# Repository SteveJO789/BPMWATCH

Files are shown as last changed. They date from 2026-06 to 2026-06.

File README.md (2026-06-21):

# BPMWATCH

BPMWATCH is a two-node wearable Radar MVP built with ESP32, B&T BU01/DW1000 ranging, GY-511 heading and motion sensing, MAX30102 heart-rate sensing, ESP-NOW Peer data, and a no-CS ZJY-IPS130-V2.0 ST7789 240x240 display.

Each node places itself at the center of a north-up radar screen and shows the other node as a distance-scaled dot. The direction is a movement-based visual estimate, not a true UWB angle measurement.

## Current Architecture

The product has two equal Radar Nodes:

| Product node | ESP32 STA MAC | Fixed DW1000 role |
|---|---|---|
| Node A | `0C:8A:D3:7C:E5:A4` | Anchor |
| Node B | `1C:75:C4:F4:E9:D4` | Tag |

Anchor and Tag are radio protocol roles only. There is no application-level Master or Slave.

The two links have separate responsibilities:

- **UWB:** calibrated distance ranging only.
- **ESP-NOW:** Peer BPM and accepted reciprocal-bearing estimates.

Production firmware will not create a Wi-Fi AP, webserver, or browser dashboard. The existing AP monitor remains only in the diagnostic `uwb_pair_test`.

See:

- [Architecture workflow](radar_2d_map_architecture.svg)
- [Architecture](docs/architecture.md)
- [Radar MVP design spec](docs/superpowers/specs/2026-06-21-radar-2d-map-mvp-design.md)
- [Test plan](docs/test-plan.md)

## Hardware Per Node

- ESP32-WROOM-32
- B&T BU01 DW1000 LDO UWB breakout
- ZJY-IPS130-V2.0 IPS TFT LCD 240x240 ST7789 display without a CS pin
- GY-511 / LSM303DLHC accelerometer and compass
- MAX30102 heart-rate sensor
- 602030 Li-Po battery
- TP4056 Type-C charger with protection
- TPS63802 3.3V buck-boost supply
- Power switch, decoupling capacitors, and enclosure

Both nodes use the same buses and pin map. Only the MAC address and fixed DW1000 role differ.

## Radar Behavior

- North-up display with the current node at `(120,120)`.
- UWB distance is filtered with an EMA and mapped to an automatic `5/10/20/40m` range.
- GY-511 acceleration and compass heading provide a visual movement-bearing heuristic.
- Decreasing distance places the Peer along the estimated movement bearing.
- Increasing distance places the Peer approximately 180 degrees behind that bearing.
- ESP-NOW mirrors an accepted bearing to the other display with a reciprocal 180-degree transform.
- If UWB is lost, the last Peer dot remains as an inactive outline.
- If ESP-NOW is stale, radar ranging continues and Peer BPM displays `--`.

## Repository Map

- `firmware/radar_node`: approved production target; implementation pending.
- `firmware/tests/uwb_pair_test`: working two-node UWB diagnostic with AP monitor.
- `firmware/tests`: focused hardware bring-up projects.
- `firmware/master` and `firmware/slave`: deprecated pre-pivot production scaffolds; scheduled for legacy relocation during firmware implementation.
- `firmware/sim/wokwi`: legacy three-node UI simulation; not current Radar MVP validation.
- `lib/DW1000`: vendored ESP32-compatible DW1000 library.
- `docs/legacy/three-node`: superseded triangle-map documents and diagrams.
- `test-logs`: current two-node bench evidence.

## Current Status

Completed:

- ESP32 identity and STA MAC capture.
- ZJY-IPS130-V2.0 display bring-up using dedicated `SPIClass`, manual reset, `SPI_MODE3`, and 8 MHz display transactions.
- GY-511 I2C discovery, initialization, and heading output.
- MAX30102 raw IR and BPM calculation bring-up.
- Real Node A to Node B DW1000 ranging.
- Antenna delay `16555`, five-sample application median filter, and recovery behavior.
- Two-node Radar architecture, glossary, workflow SVG, and design specification.

Next implementation milestone:

1. Create the shared `firmware/radar_node` PlatformIO project.
2. Integrate UWB range callbacks without the production AP monitor.
3. Add GY-511 movement-bearing estimation and axis mapping.
4. Add ESP-NOW Peer BPM and reciprocal bearing.
5. Render and bench-test the radar on both ST7789 displays.

## Diagnostic Build

On this Windows machine, PlatformIO is available through:

```powershell
& "$env:USERPROFILE\.platformio\penv\Scripts\platformio.exe" run -d firmware\tests\uwb_pair_test -e master -e tag
```

The diagnostic environments retain the literal names `master` and `tag` for compatibility with tested code. They map to Node A/Anchor and Node B/Tag.

## Electrical Safety

- Keep all ESP32, DW1000, ST7789, GY-511, and MAX30102 signal levels 3.3V-compatible.
- Confirm the exact BU01 breakout power-input label before applying power.
- Keep the no-CS ST7789 on dedicated HSPI; do not share the DW1000 default SPI bus.
- Initialize ZJY-IPS130-V2.0 with `tft.init(240, 240, SPI_MODE3)` and call `tft.setSPISpeed(8000000)` after init.
- Feed Li-Po voltage to an ESP32 ADC only through a safe resistor divider.
- Verify TPS63802 stability during ESP32 radio and UWB current bursts.

## Historical Architecture

The former one-Master/two-Slave triangle map is no longer the product direction. Its documentation is retained under [`docs/legacy/three-node`](docs/legacy/three-node/README.md).

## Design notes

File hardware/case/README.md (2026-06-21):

# Two-Node Radar Case Design

Node A and Node B require equivalent wearable enclosures for ESP32, BU01, ST7789, GY-511, MAX30102, and the protected battery power chain.

Mechanical requirements:

- Keep ESP32 and BU01 antenna regions clear of metal and the battery.
- Keep the MAX30102 window aligned with stable skin contact.
- Mount GY-511 flat with its X/Y orientation recorded relative to display top.
- Expose the ST7789 without loading its flex cable or header.
- Provide access to charging, power, reset/boot, and any future interaction button.
- Leave room for regulator and radio decoupling capacitors.

Use the same external orientation for both nodes where possible so axis mapping and radar behavior remain consistent.

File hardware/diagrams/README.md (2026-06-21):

# Hardware Diagrams

The current system workflow is [`radar_2d_map_architecture.svg`](../../radar_2d_map_architecture.svg).

New diagrams must use Node A and Node B as equal Radar Nodes. `Anchor` and `Tag` may appear only as fixed DW1000 radio roles. Superseded three-node diagrams belong under [`docs/legacy/three-node`](../../docs/legacy/three-node/README.md).

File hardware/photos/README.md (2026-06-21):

# Two-Node Radar Hardware Photos

Store dated photos for both Node A and Node B. Each photo set should show:

- Node label and ESP32 STA MAC
- BU01 antenna orientation
- ST7789 wiring and display orientation
- GY-511 axis orientation relative to display top
- MAX30102 placement
- I2C, default SPI, and dedicated HSPI wiring
- Battery, charger, regulator, switch, and decoupling

Do not label new photos as Master or Slave. Historical photos may keep their original labels if the caption marks them as pre-pivot evidence.

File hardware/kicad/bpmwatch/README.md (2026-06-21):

# BPMWATCH KiCad Schematic Status

The KiCad files in this folder predate the 2026-06-21 two-node Radar pivot. They describe an unequal Master/repeated-Slave concept and are not the current wiring source of truth.

Use [`docs/pin-map.md`](../../../docs/pin-map.md), [`docs/wiring-node-a.md`](../../../docs/wiring-node-a.md), and [`docs/wiring-node-b.md`](../../../docs/wiring-node-b.md) for current bench wiring.

## Required Schematic Revision

The next schematic revision must contain two equivalent Radar Nodes:

- ESP32-WROOM-32
- BU01/DW1000 on default SPI
- No-CS ST7789 on dedicated HSPI
- GY-511 and MAX30102 on shared I2C GPIO21/22
- Protected Li-Po charging and TPS63802 3.3V rail

Only the node identity and fixed DW1000 Anchor/Tag role differ.

## Existing Artifact Use

The existing schematic and exports remain historical module-level interconnect references. They are not production PCB signoff, and their Master/Slave labels must not be copied into new designs.

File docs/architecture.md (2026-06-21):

# Two-Node Radar Architecture

BPMWATCH contains two equal wearable Radar Nodes. Each node displays itself at the center and the other node as its Peer.

```text
Node A / DW1000 Anchor  <--- calibrated UWB distance --->  Node B / DW1000 Tag
          |                                                       |
          +<------ ESP-NOW: Peer BPM + bearing estimate -------->+
```

Anchor and Tag are fixed DW1000 radio roles. They do not create an application-level Master/Slave hierarchy.

## Per-Node Data Flow

```text
DW1000 distance ------\
GY-511 heading --------+--> Radar state --> north-up ST7789 display
GY-511 acceleration --/

Local MAX30102 BPM --> ESP-NOW --> Peer display
Accepted bearing ----> ESP-NOW --> reciprocal angle on Peer display
```

## UWB Responsibility

UWB provides distance only. Production firmware retains the proven Anchor/Tag ranging flow, antenna delay `16555`, five-sample median filter, and recovery behavior.

UWB does not provide direction. The displayed bearing is a visual estimate derived from current-node movement and heading.

## Movement Bearing

The node uses mapped GY-511 acceleration axes to estimate a short-lived horizontal acceleration direction, then rotates that direction into a north-up compass frame.

When cumulative UWB distance changes by more than `0.25m` during accepted movement:

- Decreasing range places the Peer along the movement bearing.
- Increasing range places the Peer approximately 180 degrees behind it.
- Stable range keeps the previous Peer bearing.

If one node accepts a bearing, ESP-NOW sends it to the Peer. The Peer applies `+180 degrees` so both displays update when only one node moves.

## ESP-NOW Responsibility

ESP-NOW carries small bidirectional status packets:

- Peer BPM and validity
- Accepted bearing and validity
- Node ID, packet version, and sequence

It uses Wi-Fi station mode without creating an AP or browser UI. ESP-NOW freshness and UWB freshness are tracked separately.

## Display Meaning

- North is always at the top.
- The current node is always at the center.
- The Peer radius represents filtered UWB distance within the active `5/10/20/40m` band.
- The Peer angle is an estimate, not a measured UWB angle or geographic position.
- A gray outline dot means the last UWB position is being retained after link loss.

## Historical Architecture

The former three-node triangle solver and `TeamMapPacket` flow are superseded. Historical documents are under [`legacy/three-node`](legacy/three-node/README.md).

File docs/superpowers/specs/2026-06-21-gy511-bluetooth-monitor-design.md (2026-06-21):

# GY-511 Bluetooth Serial Monitor Design

## Goal

Allow the soldered ESP32 and GY-511 test assembly to be monitored from Windows after USB is disconnected and the board is powered from the TPS63802 3.3 V rail.

## Scope

- Modify only `firmware/tests/gy511_test/src/main.cpp`.
- Keep the existing GY-511 initialization, register reads, calculations, and 500 ms reporting interval.
- Keep USB `Serial` output available for bench diagnosis.
- Add Bluetooth Classic Serial Port Profile output for this diagnostic sketch only.
- Do not add Bluetooth to production Radar Node firmware and do not replace the planned ESP-NOW peer-data protocol.

## Runtime Design

The sketch creates an ESP32 `BluetoothSerial` endpoint named `BPMWATCH-GY511` using Secure Simple Pairing (SSP) in Just Works mode. Each startup, status, error, and sensor-data line is written to both USB `Serial` and Bluetooth serial.

Bluetooth startup failure must not block I2C setup or GY-511 sampling. The sketch reports the failure over USB and continues operating as the original USB-only sensor test.

## Data Flow

1. The ESP32 initializes USB serial.
2. It enables SSP before starting Bluetooth SPP.
3. It initializes I2C and the GY-511.
4. Every 500 ms, it reads accelerometer and magnetometer registers and calculates heading.
5. It formats one complete diagnostic line and sends the same line to both serial transports.

## Power And Connection Procedure

1. Isolate or switch off the TPS63802 output before connecting USB for upload so two regulators do not drive the same 3.3 V rail.
2. Upload the diagnostic firmware over USB.
3. Disconnect USB completely.
4. Restore TPS63802 power.
5. Pair Windows with `BPMWATCH-GY511`. No PIN is required.
6. Open the outgoing Bluetooth SPP COM port at 115200 baud. The SPP transport does not depend on UART baud electrically, but 115200 keeps terminal configuration consistent with the USB monitor.

## Verification

- The PlatformIO environment builds successfully.
- Source-level checks confirm the device name, SSP-before-startup ordering, absence of legacy PIN configuration, and dual-output behavior.
- With hardware, Windows can pair and receive GY-511 readings while USB is disconnected.
- If Bluetooth initialization fails, USB still reports the failure and GY-511 sampling continues.

## Non-Goals

- BLE support.
- A phone application or browser dashboard.
- Wi-Fi AP, webserver, or Telnet logging.
- Changes to production node-to-node communications.

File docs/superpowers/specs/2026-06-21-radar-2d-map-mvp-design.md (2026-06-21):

# Radar 2D Map MVP Design

Date: 2026-06-21

## Status

Approved design for implementation.

## Goal

Replace the product's three-node triangle-map architecture with a two-node wearable radar MVP. Each node places itself at the center of a north-up ST7789 display and shows the other node as a dot using UWB distance plus a movement-based bearing estimate.

The MVP prioritizes useful visual behavior over positioning accuracy.

## Product Decisions

- The product has exactly two equal Radar Nodes. There is no application-level master.
- Node A uses STA MAC `0C:8A:D3:7C:E5:A4` and the fixed DW1000 Anchor radio role.
- Node B uses STA MAC `1C:75:C4:F4:E9:D4` and the fixed DW1000 Tag radio role.
- Anchor and Tag are radio roles only. Product UI and documentation use Node A, Node B, current node, and Peer.
- Both nodes use ESP32, B&T BU01/DW1000, GY-511/LSM303DLHC, MAX30102, and a no-CS ZJY-IPS130-V2.0 ST7789 240x240 display.
- The existing working two-node DW1000 ranging flow, calibration, filtering, and recovery behavior remain the baseline.
- ESP-NOW carries Peer BPM and accepted bearing estimates. It does not create a Wi-Fi AP or browser UI.
- The existing `firmware/tests/uwb_pair_test` remains an unchanged diagnostic test, including its AP monitor.
- The superseded three-node production code and related artifacts move under a clearly marked legacy location during implementation.

## Non-Goals

- Three-node ranging or triangle solving
- `TeamMapPacket` or shared team-map broadcasting
- True 2D positioning
- DW1000 Angle-of-Arrival
- GPS coordinates
- Wi-Fi AP, webserver, or browser dashboard in production firmware
- Dynamic Anchor/Tag role switching
- High-accuracy inertial dead reckoning
- Accuracy warning UI
- OLED support

## Repository Shape

The canonical production firmware will be:

```text
firmware/radar_node/
|-- platformio.ini
`-- src/
    |-- main.cpp
    |-- NodeConfig.h
    |-- UwbPeerRanging.h
    |-- UwbPeerRanging.cpp
    |-- Gy511Motion.h
    |-- Gy511Motion.cpp
    |-- HeartRateSensor.h
    |-- HeartRateSensor.cpp
    |-- PeerLink.h
    |-- PeerLink.cpp
    |-- RadarMap.h
    `-- RadarMap.cpp
```

PlatformIO provides two environments from the same source:

- `node_a_anchor`
- `node_b_tag`

Build flags select the node ID, Peer STA MAC, and fixed DW1000 role. Node behavior outside the radio role is symmetric.

## Hardware and Buses

Both nodes use the same pin contract:

| Device | Interface | ESP32 pins |
|---|---|---|
| BU01/DW1000 | Default SPI | SCK 18, MISO 19, MOSI 23, CS 5, IRQ 34, RST 4 |
| ST7789 no-CS | Dedicated HSPI | SCK 14, MOSI 13, BLC 25, DC 26, RST 27 |
| GY-511 | I2C | SDA 21, SCL 22 |
| MAX30102 | Shared I2C | SDA 21, SCL 22 |

The display must remain on its dedicated `SPIClass`; the no-CS ST7789 must not share the DW1000 bus.

The bench-confirmed display initialization contract is:

1. Drive RES high, low, then high with 50 ms holds.
2. Start the dedicated HSPI bus.
3. Call `tft.init(240, 240, SPI_MODE3)`.
4. Call `tft.setSPISpeed(8000000)` after init so subsequent transactions use 8 MHz.

## Core Data Structures

The Radar module starts with the required public contracts:

```cpp
struct RadarInput {
  float distanceM;
  float headingDeg;
  float accelX;
  float accelY;
  float accelZ;
  bool linkOk;
  unsigned long timestamp;
};

struct RadarState {
  float peerAngleDeg;
  float peerDistanceM;
  float lastDistanceM;
  float smoothedDistanceM;
  bool hasAngle;
  bool hidePeerDot;
  unsigned long lastUpdate;
};
```

Internal state may extend `RadarState` or remain private to `RadarMap` for movement filtering, distance baseline, auto-range hysteresis, last valid link state, and accepted-bearing publication. Peer BPM and ESP-NOW freshness remain outside `RadarInput` because they do not affect radar geometry.

## Sensor Sampling

- MAX30102 sampling remains near 20 ms so beat detection is not slowed by UI or packet timing.
- GY-511 is sampled independently from the 150 ms display cadence.
- GY-511 and MAX30102 share I2C without blocking the UWB ranging loop.
- Configurable compile-time axis mapping supports X/Y swap and sign inversion.
- The initial mounting convention is mapped `+Y = display top`.

## Movement Bearing Heuristic

The GY-511 does not contain a gyroscope, so the MVP does not claim reliable inertial navigation. It uses a short-lived horizontal-acceleration direction as a visual movement heuristic:

1. Apply axis mapping.
2. Low-pass accelerometer axes to estimate gravity.
3. Subtract gravity to obtain approximate linear acceleration.
4. Reject weak acceleration as stationary/noisy.
5. For accepted motion, compute the relative direction with `atan2(rightAccel, forwardAccel)`.
6. Add compass heading and normalize to produce a north-up movement bearing.
7. Keep the last accepted movement bearing while acceleration becomes weak.

The first implementation uses test-tunable constants for the gravity filter, motion threshold, confirmation samples, and motion hold time. Bench tests, not theoretical precision, determine their final values.

## Distance and Bearing Update

For each valid UWB distance:

```cpp
smoothedDistanceM = smoothedDistanceM * 0.75f + distanceM * 0.25f;
```

The first valid sample initializes the EMA directly to avoid ramping from zero.

The distance delta is cumulative since the last accepted bearing update, not merely the difference between adjacent 100-200 ms samples:

```cpp
delta = smoothedDistanceM - lastDistanceM;
```

When recent motion is valid and `abs(delta) > 0.25m`:

- `delta < 0`: target Peer angle is the movement bearing.
- `delta > 0`: target Peer angle is the movement bearing plus 180 degrees.
- Smooth toward the target with shortest-path angular smoothing and alpha `0.15`.
- Set the new smoothed distance as the next bearing baseline.
- Publish the accepted bearing to the Peer through ESP-NOW.

If no angle exists after the first valid range, initialize `peerAngleDeg` from the current compass heading. If distance change is below the threshold, keep the previous Peer angle.

Required helpers are:

- `normalizeAngle(float angle)`
- `angleDiff(float a, float b)`
- `smoothAngle(float current, float target, float alpha)`
- `mapDistanceToRadius(float distanceM)`
- `updateRadarState(RadarInput input)`
- `drawRadarMap()`

## Reciprocal Bearing

When one node accepts a new Peer bearing `theta`, it sends that estimate through ESP-NOW. The receiving node stores `normalizeAngle(theta + 180 degrees)` so both displays update even when only one node is moving.

The MVP primarily supports one moving node at a time. If both move and produce conflicting estimates, the newest locally received estimate wins; temporary dot movement is accepted as an MVP limitation.

## Auto-Range

The radar uses discrete ranges:

```text
5 m -> 10 m -> 20 m -> 40 m
```

- Expand immediately when smoothed distance exceeds 90% of the current range.
- Shrink one or more bands only after distance remains below 35% for 10 seconds.
- Do not change range while UWB is lost.
- Display the active range as `R:5m`, `R:10m`, `R:20m`, or `R:40m`.

The radial conversion is:

```cpp
radiusPx = constrain(
    (smoothedDistanceM / currentRangeM) * radarRadiusPx,
    5.0f,
    radarRadiusPx);
```

## Screen Geometry and Rendering

The only supported display is the no-CS ZJY-IPS130-V2.0 ST7789 240x240:

- Center: `(120, 120)`
- Radar radius: `100 px`
- North-up orientation
- Angle `0 degrees`: top
- Angle `90 degrees`: right

Polar conversion is:

```cpp
angleRad = peerAngleDeg * DEG_TO_RAD;
peerX = centerX + radiusPx * sinf(angleRad);
peerY = centerY - radiusPx * cosf(angleRad);
```

Each frame contains:

- Outer radar circle
- Inner half-range circle
- Horizontal and vertical cross lines
- `N` marker
- Green center dot for the current node
- Orange filled Peer dot when UWB is valid
- Gray outline Peer dot at the last known position when UWB is lost
- `WAITING` and no Peer dot before the first valid range
- Node label, UWB status, and active range at the top
- Peer BPM and distance at the bottom

The screen updates every 150 ms using one display SPI transaction per frame. Production rendering has no accuracy warning screen.

## UWB Ranging

Production code reuses the proven behavior from `firmware/tests/uwb_pair_test`:

- Fixed Anchor and Tag roles
- Antenna delay `16555`
- Application median filter with five samples
- Raw range, RX power, and quality callbacks
- Discovery recovery after 5 seconds
- Post-connection recovery after 15 seconds

The production module removes AP/webserver responsibilities. The diagnostic test retains them.

If no valid range arrives for 3 seconds, UI state becomes `UWB LOST`. The last known dot remains indefinitely until a new range arrives or the node restarts.

## ESP-NOW Peer Link

ESP-NOW is a bidirectional data link. It uses Wi-Fi station mode but does not create an AP.

```cpp
struct PeerStatusPacket {
  uint8_t version;
  uint8_t senderNodeId;
  uint16_t sequence;
  uint16_t bpm;
  float peerBearingDeg;
  uint8_t flags;
};
```

Flags indicate `bpmValid` and `bearingValid`.

- Send status every 500 ms.
- Send immediately after accepting a new bearing.
- Use local receive time for freshness rather than comparing unsynchronized node clocks.
- If no Peer packet arrives for 3 seconds, display `PEER BPM:--`.
- If MAX30102 has no valid finger/beat result, send `bpmValid=false`.
- UWB and ESP-NOW statuses are independent.

## Main Loop Scheduling

The loop remains non-blocking:

1. Poll DW1000 continuously.
2. Sample MAX30102 near every 20 ms.
3. Sample GY-511 at its configured sensor cadence.
4. Process ESP-NOW callbacks without blocking.
5. Update Radar state and render every 150 ms.
6. Send periodic Peer status every 500 ms.
7. Send accepted bearing events immediately.

No sensor sampling rate is reduced to control Serial output. Logs are throttled separately.

## Failure Behavior

| Failure | Radar behavior |
|---|---|
| No UWB range has ever arrived | No Peer dot; show `WAITING` |
| UWB range stale for 3 seconds | Keep last dot as gray outline; show `UWB LOST` |
| ESP-NOW stale for 3 seconds | Keep radar behavior; show `PEER BPM:--` |
| MAX30102 has no valid BPM | Send invalid BPM; Peer shows `PEER BPM:--` |
| GY-511 init/read failure | Keep distance and last angle; report sensor error through UI/Serial |
| Both nodes move simultaneously | Newest received bearing estimate wins; temporary instability is accepted |

## Documentation Migration

Implementation updates the current source of truth to the two-node architecture:

- `README.md`
- `docs/architecture.md`
- `docs/bom.md`
- `docs/pin-map.md`
- `docs/ranging-protocol.md`
- `docs/test-plan.md`
- wiring documentation
- main project plan

The new workflow diagram is `radar_2d_map_architecture.svg`. The old three-node SVG, triangle-map documentation, and production code move to a clearly named legacy area instead of being deleted.

## Verification

Automated tests cover:

- Angle normalization and wrap-around
- Shortest-path angle difference and smoothing
- EMA initialization and update
- Cumulative 0.25 m bearing baseline
- Motion gating and axis mapping
- Reciprocal bearing
- Auto-range hysteresis
- UWB-lost dot persistence
- ESP-NOW BPM freshness

Build gates are:

- `node_a_anchor`
- `node_b_tag`
- diagnostic `uwb_pair_test` master
- diagnostic `uwb_pair_test` tag

Bench verification covers:

1. Existing UWB pair ranging behavior
2. GY-511 axis mapping
3. Node A moving while Node B remains still
4. Node B moving while Node A remains still
5. Decreasing and increasing distance behavior
6. Bearing persistence when distance is stable
7. UWB loss with persistent inactive dot
8. ESP-NOW loss with invalid Peer BPM only
9. Bidirectional Peer BPM display
10. Auto-range bands and hysteresis

Results are stored in a new Radar MVP test log.

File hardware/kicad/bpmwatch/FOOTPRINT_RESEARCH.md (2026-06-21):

# Two-Node Radar Footprint Research

Research baseline: 2026-06-09. Architecture updated: 2026-06-21.

The current target has two equivalent Radar Nodes. Exact purchased breakouts must be measured before assigning production footprints.

| Module per node | Qty total | Footprint direction | Status |
|---|---:|---|---|
| ESP32-WROOM-32 | 2 | `RF_Module:ESP32-WROOM-32` only for a bare castellated module; use the exact dev-board headers otherwise | Confirm board variant |
| BU01 UWB breakout | 2 | Custom footprint from the exact BU01 package drawing | Confirm pad pattern and antenna keepout |
| ZJY-IPS130-V2.0 no-CS ST7789 240x240 | 2 | Measure the purchased header count, board outline, and mounting holes | Existing schematic symbol may not match |
| MAX30102 breakout | 2 | Custom breakout/header footprint from measured board | Confirm row spacing and orientation |
| GY-511 / LSM303DLHC | 2 | Header plus measured board outline | Confirm header direction and axis marking |
| Protected TP4056 Type-C module | 2 | Custom module footprint matching exact IN/BAT/OUT pads | Board variants differ |
| TPS63802 module | 2 | Custom breakout footprint; do not substitute bare-IC layout without a regulator redesign | Vendor/module not yet identified |
| 602030 Li-Po connector | 2 | Exact connector, JST-PH only if confirmed | Battery body is a mechanical keepout |
| Power switch | 2 | Exact purchased switch footprint | Confirm pitch and actuator direction |
| Battery divider resistors | 4 | 0805 recommended for hand assembly | Values selected during ADC design |
| Bulk/local capacitors | Per rail | 0805/1206 according to capacitance and voltage | Validate under radio bursts |

## Sources Previously Checked

- KiCad official `RF_Module`, connector, switch, resistor, and capacitor libraries
- Ai-Thinker BU01 public dimensions and SPI interface information
- ST7789 240x240 module references
- MAX30102 breakout references
- GY-511 / LSM303DLHC module references
- TP4056 protection module references
- Texas Instruments TPS63802 documentation

## Blockers Before PCB Layout

1. Regenerate the schematic as two equivalent Radar Nodes instead of the pre-pivot Master/Slave drawing.
2. Confirm every purchased breakout's dimensions, header count, and pin order.
3. Decide whether the PCB carries bare modules or sockets for development breakouts.
4. Add ESP32 and BU01 antenna keepouts.
5. Add battery, display, sensor-contact, and enclosure mechanical constraints.
6. Validate power integrity during simultaneous ESP-NOW, UWB, display, and sensor activity.

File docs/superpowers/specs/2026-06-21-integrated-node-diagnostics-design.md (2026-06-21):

# Integrated Node Diagnostics Design

Date: 2026-06-21

## Status

Approved design for implementation.

## Goal

Create a two-node hardware integration test that runs the ST7789 display, GY-511, MAX30102, and the proven DW1000 pair-ranging flow together. The 240x240 display replaces Bluetooth as the primary field diagnostic output.

This phase validates complete-node operation before Radar map geometry, ESP-NOW, and Peer BPM are introduced.

## Scope

- Create `firmware/tests/integrated_node_test` without changing the focused module tests.
- Build the same source as `node_a_anchor` and `node_b_tag`.
- Display live local hardware values only; do not use mock values.
- Preserve the current two-node ranging roles, calibration, median filter, callbacks, and recovery behavior from `firmware/tests/uwb_pair_test`.
- Use the user's current MAX30102 beat-detection behavior, including the four-sample average.
- Use the confirmed GY-511 register configuration and heading calculation from `firmware/tests/gy511_test`.
- Use the confirmed ZJY-IPS130-V2.0 ST7789 initialization from `firmware/tests/st7789_display_test`.

## Non-Goals

- Radar map rendering or bearing estimation
- ESP-NOW or Peer BPM exchange
- Bluetooth Classic, BLE, Wi-Fi AP, webserver, or browser monitoring
- Changes to the focused UWB, GY-511, MAX30102, or display test sketches
- Reuse of the obsolete three-node `firmware/slave` or `firmware/master` architecture

## Repository Shape

```text
firmware/tests/integrated_node_test/
|-- platformio.ini
`-- src/
    |-- main.cpp
    |-- NodeConfig.h
    |-- DiagnosticsState.h
    |-- DiagnosticsDisplay.h
    |-- DiagnosticsDisplay.cpp
    |-- Gy511Sensor.h
    |-- Gy511Sensor.cpp
    |-- Max30102Sensor.h
    |-- Max30102Sensor.cpp
    |-- UwbDiagnostics.h
    `-- UwbDiagnostics.cpp
```

Each module owns one hardware responsibility. `main.cpp` initializes the shared buses and runs the non-blocking scheduler.

## Build Environments

`node_a_anchor` defines Node A and the fixed DW1000 Anchor radio role:

- Node label: `NODE A / ANCHOR`
- EUI: `0C:8A:D3:7C:E5:A4:00:01`
- Antenna delay: `16555`

`node_b_tag` defines Node B and the fixed DW1000 Tag radio role:

- Node label: `NODE B / TAG`
- EUI: `1C:75:C4:F4:E9:D4:00:01`
- Antenna delay: `16555`

Anchor and Tag are radio roles only. This test does not introduce an application master.

## Hardware And Buses

The shared pin contract is:

| Device | Interface | Pins |
|---|---|---|
| BU01/DW1000 | Default SPI | SCK 18, MISO 19, MOSI 23, CS 5, IRQ 34, RST 4 |
| ST7789 no-CS | Dedicated HSPI | SCK 14, MOSI 13, BLC 25, DC 26, RST 27 |
| GY-511 | Shared I2C | SDA 21, SCL 22 |
| MAX30102 | Shared I2C | SDA 21, SCL 22 |

`Wire.begin(21, 22)` is called once. GY-511 uses addresses `0x19` and `0x1E`; MAX30102 uses `0x57`.

The no-CS display never shares the DW1000 SPI bus. Display startup uses:

1. Backlight high.
2. Manual reset high, low, high with 50 ms holds.
3. Dedicated HSPI startup.
4. `tft.init(240, 240, SPI_MODE3)`.
5. `tft.setSPISpeed(8000000)` after initialization.

## Module Responsibilities

### UwbDiagnostics

- Initialize default SPI and DW1000 communication.
- Confirm the printable device identifier begins with `DECA`.
- Use fixed Anchor or Tag role selected at compile time.
- Use antenna delay `16555` and `DW1000.MODE_LONGDATA_RANGE_ACCURACY`.
- Preserve the five-sample application median filter and disable the library range filter.
- Preserve new-range, new-device, blink where supported, and inactive-device callbacks.
- Preserve the current discovery and connected recovery behavior from `uwb_pair_test` without adding Wi-Fi responsibilities.
- Expose SPI readiness, Peer presence, filtered distance, range freshness, and recovery count to the display state.

### Gy511Sensor

- Initialize the accelerometer at `0x19` and magnetometer at `0x1E` with the confirmed register values.
- Sample without blocking the UWB loop.
- Expose initialization/read status, heading in `0-359.9` degrees, and raw accelerometer X/Y/Z values.
- A read failure changes only GY-511 state; it does not stop other modules.

### Max30102Sensor

- Initialize through the shared `Wire` bus at fast I2C speed.
- Preserve the current LED setup and `checkForBeat()` behavior.
- Sample near every 20 ms without `delay(20)` in the main loop.
- Accept measured BPM from 40 through 220 and expose the four-valid-sample average.
- Expose initialization state, raw IR, average BPM, and finger presence using the current `IR >= 50000` threshold.
- Initialization failure changes only MAX30102 state.

### DiagnosticsDisplay

- Initialize the exact ST7789 module using the confirmed reset, mode, and speed sequence.
- Draw a fixed dashboard layout once and refresh only value regions to reduce flicker.
- Render green for valid operation, orange for waiting/no-finger states, and red for errors.
- Continue rendering available modules when another module fails.

## Dashboard

The single dashboard page shows:

- Header: `NODE A / ANCHOR` or `NODE B / TAG`
- UWB: `OK`, `WAIT`, `LOST`, or `SPI ERR`, plus filtered distance
- GY-511: `OK` or `READ ERR`, heading, and accelerometer X/Y/Z
- MAX30102: `OK`, `NO FINGER`, or `ERR`, raw IR, and average BPM

The display contains no Radar geometry, mock Peer, accuracy warning, or browser connection instructions.

## Scheduling

The loop remains non-blocking:

1. Poll `DW1000Ranging.loop()` continuously.
2. Update MAX30102 near every 20 ms.
3. Update GY-511 every 50 ms.
4. Refresh display values every 200 ms.
5. Emit a combined Serial diagnostic line every 1000 ms.

All timing uses elapsed `millis()` checks. Display and Serial cadence never controls sensor sampling or UWB polling.

## Failure Behavior

| Failure | Display behavior | Remaining system |
|---|---|---|
| DW1000 identifier is not `DECA` | `UWB SPI ERR`, distance `--` | Display and I2C sensors continue |
| Peer has not ranged yet | `UWB WAIT`, distance `--` | All local sensors continue |
| Last valid range is older than 3 seconds | `UWB LOST`, keep last distance visible | Recovery behavior remains active |
| GY-511 initialization or read fails | `GY READ ERR`, heading/accel `--` | UWB, MAX30102, display continue |
| MAX30102 initialization fails | `MAX ERR`, IR/BPM `--` | UWB, GY-511, display continue |
| MAX30102 has no finger | `MAX NO FINGER`, BPM `--` | Raw IR and other modules continue |

## Verification

Automated/source checks verify:

- Both PlatformIO environments exist with the correct role and EUI flags.
- Display and DW1000 use separate SPI instances and the confirmed ST7789 initialization sequence.
- I2C is initialized once on GPIO21/22.
- Bluetooth, BLE, Wi-Fi AP, and webserver headers or startup calls are absent.
- The scheduler contains no `delay(20)` sensor loop.
- Both environments compile successfully.

Bench verification runs in this order:

1. Boot each node with its Peer off and confirm `UWB WAIT` while local sensors update.
2. Start the Peer and confirm filtered distance updates on both displays.
3. Rotate and tilt each node and confirm heading and acceleration change.
4. Place and remove a finger and confirm IR/BPM/no-finger behavior.
5. Interrupt each sensor or Peer separately and confirm error isolation.
6. Run both complete nodes together and watch for display flicker, stalled ranging, resets, and TPS63802 instability.

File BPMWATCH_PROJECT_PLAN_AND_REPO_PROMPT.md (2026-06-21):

# BPMWATCH Two-Node Radar MVP Project Plan

## Product Goal

Build two equal wearable Radar Nodes. Each node displays itself at the center of a north-up ST7789 radar and shows the other node using calibrated UWB distance plus a movement-based bearing estimate.

The MVP targets clear visual behavior, not accurate 2D localization.

## Fixed Decisions

- Exactly two Radar Nodes: Node A and Node B.
- No application-level Master or Slave.
- Node A uses the fixed DW1000 Anchor radio role.
- Node B uses the fixed DW1000 Tag radio role.
- Both nodes have ESP32, BU01/DW1000, ST7789, GY-511, and MAX30102.
- UWB carries distance only.
- ESP-NOW carries Peer BPM and reciprocal-bearing estimates.
- Production firmware has no AP, webserver, or browser dashboard.
- The display is the no-CS ZJY-IPS130-V2.0 ST7789 240x240; OLED support is outside the MVP.
- The old three-node triangle architecture is legacy.

## Node Identity

| Node | STA MAC | DW1000 role | Product relationship |
|---|---|---|---|
| Node A | `0C:8A:D3:7C:E5:A4` | Anchor | Equal Radar Node |
| Node B | `1C:75:C4:F4:E9:D4` | Tag | Equal Radar Node |

## Hardware Contract

Each node contains:

- ESP32-WROOM-32
- B&T BU01 DW1000 LDO UWB breakout
- No-CS ZJY-IPS130-V2.0 ST7789 240x240 display
- GY-511 / LSM303DLHC
- MAX30102
- 602030 Li-Po, protected TP4056 charger, TPS63802 3.3V supply, and power switch

Bus allocation:

- DW1000 default SPI: `SCK=18`, `MISO=19`, `MOSI=23`, `CS=5`, `IRQ=34`, `RST=4`
- ST7789 dedicated HSPI: `SCK=14`, `MOSI=13`, `BLC=25`, `DC=26`, `RST=27`
- Shared sensor I2C: `SDA=21`, `SCL=22`

Display initialization contract:

- Pulse RES high/low/high before initialization.
- Call `tft.init(240, 240, SPI_MODE3)`.
- Call `tft.setSPISpeed(8000000)` after initialization.

## Production Firmware Target

```text
firmware/radar_node/
|-- platformio.ini
`-- src/
    |-- main.cpp
    |-- NodeConfig.h
    |-- UwbPeerRanging.h/.cpp
    |-- Gy511Motion.h/.cpp
    |-- HeartRateSensor.h/.cpp
    |-- PeerLink.h/.cpp
    `-- RadarMap.h/.cpp
```

One source tree builds two environments:

- `node_a_anchor`
- `node_b_tag`

## Radar Rules

- Update state and screen every 150 ms.
- Filter distance with `previous * 0.75 + measured * 0.25`.
- Compare distance against the baseline from the last accepted bearing update.
- Require cumulative distance change greater than `0.25m` plus detected movement.
- Use motion bearing when distance decreases and motion bearing plus 180 degrees when distance increases.
- Smooth angles through the shortest path with alpha `0.15`.
- Keep a previous angle when distance is stable.
- Use north-up coordinates with self at the center.
- Auto-range through `5m`, `10m`, `20m`, and `40m` bands.
- Keep the last dot indefinitely as an inactive outline after UWB loss.
- Show Peer BPM only; display `--` when ESP-NOW data is stale.

## Milestones

### 1. Hardware Bring-Up

- [x] Identify both ESP32 STA MAC addresses.
- [x] Validate ZJY-IPS130-V2.0 wiring, dedicated HSPI, manual reset, `SPI_MODE3`, and 8 MHz transactions.
- [x] Detect GY-511 at `0x19` and `0x1E`.
- [x] Detect MAX30102 at `0x57`.
- [x] Calculate BPM from MAX30102 test firmware.
- [ ] Add ST7789, GY-511, and MAX30102 to Node A hardware.
- [ ] Confirm both nodes use identical current pin wiring.

### 2. UWB Pair Ranging

- [x] Range the current Node A/Anchor and Node B/Tag pair.
- [x] Calibrate antenna delay to `16555`.
- [x] Add five-sample application median filtering.
- [x] Validate adaptive recovery.
- [x] Record results from 1m through 20m.
- [ ] Reconfirm ranging after both nodes carry the complete display and sensor load.

### 3. Shared Radar Firmware

- [ ] Create `firmware/radar_node`.
- [ ] Build both node environments from common sources.
- [ ] Extract proven UWB behavior without production AP/web code.
- [ ] Keep `uwb_pair_test` unchanged as diagnostic tooling.

### 4. Motion Bearing

- [ ] Add configurable GY-511 axis mapping.
- [ ] Separate approximate gravity from horizontal acceleration.
- [ ] Detect movement and retain the last accepted movement bearing.
- [ ] Apply cumulative distance delta and angular smoothing.
- [ ] Document simultaneous movement as an accepted MVP limitation.

### 5. ESP-NOW Peer Data

- [ ] Exchange valid Peer BPM every 500 ms.
- [ ] Exchange accepted bearing estimates immediately.
- [ ] Apply reciprocal bearing on the receiving node.
- [ ] Track ESP-NOW freshness independently from UWB freshness.

### 6. Radar Display

- [ ] Draw outer and inner circles, cross lines, north marker, self dot, and Peer dot.
- [ ] Add automatic range bands with hysteresis.
- [ ] Show `UWB LOST` while preserving the last dot.
- [ ] Show `PEER BPM:--` when Peer data is stale.
- [ ] Verify both displays update without unacceptable flicker.

### 7. Power and Field Validation

- [ ] Validate TPS63802 output during UWB and ESP-NOW activity.
- [ ] Run each complete node on battery for 30 minutes.
- [ ] Run the pair for one hour.
- [ ] Test movement, body obstruction, trees, and link recovery.

## Acceptance Criteria

- Both nodes build from the same production source.
- UWB ranging continues with the calibrated pair behavior.
- Each display shows self at center and the Peer at distance-scaled coordinates.
- One moving node can update both screens through reciprocal bearing exchange.
- UWB loss preserves an inactive last-known dot.
- Peer BPM arrives over ESP-NOW in both directions.
- No production AP, webserver, or browser UI exists.

## Source of Truth

- `CONTEXT.md`
- `README.md`
- `radar_2d_map_architecture.svg`
- `docs/architecture.md`
- `docs/superpowers/specs/2026-06-21-radar-2d-map-mvp-design.md`
- `docs/test-plan.md`

Superseded three-node material is preserved under `docs/legacy/three-node/`.

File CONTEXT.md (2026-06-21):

# BPMWATCH Radar Context

BPMWATCH is a two-node wearable radar system. Each node shows itself at the center of a north-up display and estimates the direction and distance of the other node.

## Language

**Radar Node**:
One of the two equal wearable devices in the product. Each Radar Node has UWB ranging, motion and heading sensing, heart-rate sensing, and a display.
_Avoid_: Master, Slave, tracker

**Node A**:
The Radar Node using ESP32 STA MAC `0C:8A:D3:7C:E5:A4`. It has the fixed DW1000 Anchor radio role, but it is not an application-level master.
_Avoid_: Master Node

**Node B**:
The Radar Node using ESP32 STA MAC `1C:75:C4:F4:E9:D4`. It has the fixed DW1000 Tag radio role, but it is not an application-level slave.
_Avoid_: Slave 1

**Peer**:
The other Radar Node from the current node's point of view.
_Avoid_: Remote slave, tracked node

**Radar Bearing**:
The estimated north-up angle from the current node to its Peer. It is a visual movement-based estimate, not an angle measured by the DW1000.
_Avoid_: UWB angle, true bearing

**Peer BPM**:
The heart-rate value measured by the Peer and received over the peer data link.
_Avoid_: Local BPM

**Legacy Three-Node Map**:
The superseded architecture that used one master, two slaves, three UWB distances, and a shared triangle map.
_Avoid_: Current architecture

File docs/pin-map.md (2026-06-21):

# Two-Node Radar Pin Map

Node A and Node B use the same signal wiring. Only the ESP32 STA MAC and fixed DW1000 role differ.

## Shared Pin Contract

| Function | ESP32 pin | Bus/notes |
|---|---:|---|
| BU01 SPI SCK | GPIO18 | Default global `SPI` |
| BU01 SPI MISO | GPIO19 | Default global `SPI` |
| BU01 SPI MOSI | GPIO23 | Default global `SPI` |
| BU01 SPI CS/SS | GPIO5 | DW1000 chip select |
| BU01 IRQ | GPIO34 | Input-only interrupt pin |
| BU01 RST | GPIO4 | DW1000 reset |
| ST7789 SCL/SCK | GPIO14 | Dedicated `HSPI` / `SPIClass` |
| ST7789 SDA/MOSI | GPIO13 | Dedicated `HSPI` / `SPIClass` |
| ST7789 BLC | GPIO25 | Backlight control |
| ST7789 DC | GPIO26 | Display data/command |
| ST7789 RES | GPIO27 | Display reset |
| GY-511 SDA | GPIO21 | Shared I2C data |
| GY-511 SCL | GPIO22 | Shared I2C clock |
| MAX30102 SDA | GPIO21 | Shared I2C data |
| MAX30102 SCL | GPIO22 | Shared I2C clock |
| Battery ADC | Not assigned | Add a 3.3V-safe resistor divider before selection |
| Optional button | Not assigned | Use a pull-up/pull-down and debounce when added |

## Node Identity

| Product node | Node ID | ESP32 STA MAC | Fixed DW1000 role |
|---|---:|---|---|
| Node A | 0 | `0C:8A:D3:7C:E5:A4` | Anchor |
| Node B | 1 | `1C:75:C4:F4:E9:D4` | Tag |

The old `FC:FA:31:FE:8C:E0` board is outside the current two-node product and may be retained as a spare.

## Bus Rules

- The vendored DW1000 library owns default global `SPI`.
- The no-CS ST7789 must stay on dedicated HSPI because it cannot be deselected on a shared bus.
- The confirmed ZJY-IPS130-V2.0 initialization uses a manual RES pulse, `SPI_MODE3`, and 8 MHz transactions set through `tft.setSPISpeed(8000000)` after `init()`.
- GY-511 uses `0x19` and `0x1E`; MAX30102 uses `0x57`, so they can share I2C GPIO21/22.
- All module signal levels must remain 3.3V-compatible.

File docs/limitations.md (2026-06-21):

# Radar MVP Limitations

- The Peer angle is a movement-based visual estimate, not a DW1000 Angle-of-Arrival measurement.
- GY-511 has no gyroscope. Horizontal acceleration direction can be noisy and is not reliable dead reckoning.
- Accelerometer direction represents acceleration, not continuous walking velocity.
- The MVP primarily assumes one node moves at a time. Simultaneous movement can produce competing bearing estimates.
- GY-511 mounting orientation must be confirmed through configurable axis mapping.
- Compass readings require real-device calibration and are affected by nearby current, magnets, metal, and enclosure layout.
- UWB antenna orientation, body obstruction, trees, walls, metal, and weak power rails affect range continuity.
- The automatic radar scale changes visual radius; the active `R:5/10/20/40m` label must be read with the dot.
- A retained gray dot after `UWB LOST` is the last estimate, not a live position.
- ESP-NOW Peer BPM freshness is independent from UWB ranging status.
- MAX30102 readings are not medical-grade measurements.
- Battery percentage is an estimate until calibrated against the real discharge curve.
- The current KiCad schematic predates the two-equivalent-node pivot and must not be treated as production wiring.

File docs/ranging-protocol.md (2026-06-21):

# Two-Node Communication Protocol

The current product uses two independent links between Node A and Node B.

## UWB Distance Link

| Node | Fixed role | EUI base |
|---|---|---|
| Node A | Anchor | `0C:8A:D3:7C:E5:A4` |
| Node B | Tag | `1C:75:C4:F4:E9:D4` |

The tested ranging sequence remains:

```text
BLINK -> RANGING_INIT -> POLL -> RANGE_REPORT
```

Current ranging constants:

- `DW1000.MODE_LONGDATA_RANGE_ACCURACY`
- Antenna delay `16555`
- Application median filter: 5 accepted samples
- Discovery recovery: 5000 ms
- Connected recovery: 15000 ms

The production UI marks UWB stale after 3000 ms without a valid range, but keeps the last Peer dot indefinitely as an inactive outline.

## ESP-NOW Peer Data Link

ESP-NOW operates in Wi-Fi station mode without an AP.

```cpp
struct PeerStatusPacket {
  uint8_t version;
  uint8_t senderNodeId;
  uint16_t sequence;
  uint16_t bpm;
  float peerBearingDeg;
  uint8_t flags;
};
```

Flags identify valid BPM and valid bearing fields.

- Send status every 500 ms.
- Send immediately when a bearing estimate is accepted.
- Use local packet-receive time for freshness.
- Mark Peer BPM unavailable after 3000 ms without a packet.
- On a valid received bearing, display `normalizeAngle(peerBearingDeg + 180)`.

## Independent Failure States

| UWB | ESP-NOW | Display behavior |
|---|---|---|
| Current | Current | Active Peer dot and Peer BPM |
| Stale | Current | Inactive last-known dot and current Peer BPM |
| Current | Stale | Active Peer dot and `PEER BPM:--` |
| Stale | Stale | Inactive last-known dot and `PEER BPM:--` |

## Diagnostic Compatibility

`firmware/tests/uwb_pair_test` keeps the tested environment names `master` and `tag`, plus its AP monitor. In current terminology these map to Node A/Anchor and Node B/Tag. The AP is diagnostic-only and is not part of production firmware.

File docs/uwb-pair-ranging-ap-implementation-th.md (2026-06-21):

# คู่มือ Diagnostic UWB Pair Ranging และ Web Monitor ผ่าน Wi-Fi AP

คู่มือนี้อธิบาย diagnostic `uwb_pair_test` ของ S.T.A.T สำหรับ ESP32 2 ตัวและ B&T BU01 DW1000 LDO 2 ตัว โดยใช้ SPI สำหรับ UWB และให้ฝั่ง Anchor สร้าง Wi-Fi AP สำหรับดูค่าระยะผ่านเว็บเบราว์เซอร์

> AP และ web monitor ในเอกสารนี้เป็นเครื่องมือ diagnostic เท่านั้น Production Radar firmware ใช้ Node A/Node B, ไม่มี application-level Master/Slave และไม่มี AP/webserver

คู่ที่ทดสอบแล้วคือ `Node A/Anchor <-> Node B/Tag` โดยใช้ antenna delay `16555` และ application median filter 5 samples

## ไฟล์ที่เกี่ยวข้อง

- PlatformIO source: `firmware/tests/uwb_pair_test/src/main.cpp`
- PlatformIO config: `firmware/tests/uwb_pair_test/platformio.ini`
- Arduino IDE sketch: `arduino/uwb_pair_test_arduino/uwb_pair_test_arduino.ino`
- DW1000 library ที่ patch แล้ว: `lib/DW1000`

## หลักการทำงาน

- Node A ทำงานเป็น UWB Anchor
- Node B ทำงานเป็น UWB Tag
- ทั้งสอง node ใช้ `DW1000.MODE_LONGDATA_RANGE_ACCURACY`
- calibrated build ใช้ antenna delay `16555` และ application median filter 5 samples
- Anchor recovery ใช้ timeout 5 วินาทีก่อนเคยเชื่อมต่อ และ 15 วินาทีหลังเคยเชื่อมต่อ
- เว็บแสดง `STALE` พร้อมค่าล่าสุดระหว่าง packet gap และนับ sample ที่ถูกปฏิเสธ
- Anchor ฝั่ง diagnostic สร้าง Wi-Fi AP ชื่อ `S.T.A.T-UWB`
- เว็บมอนิเตอร์อ่านข้อมูลจาก `/api/status` ทุก 500 ms
- Serial Monitor ของทั้งสอง node แสดง distance, RX power และ quality

ค่าที่กำหนดไว้ในโค้ด:

| รายการ | ค่า |
|---|---|
| Node A / Anchor EUI | `0C:8A:D3:7C:E5:A4:00:01` |
| Node B / Tag EUI | `1C:75:C4:F4:E9:D4:00:01` |
| Wi-Fi AP | `S.T.A.T-UWB` |
| Password | `statuwb123` |
| Web monitor | `http://192.168.4.1` |
| Serial baud rate | `115200` |
| Calibration antenna delay | `16555` |
| Range filter | Application median 5 samples |
| Anchor recovery timeout | Discovery `5000 ms`, connected `15000 ms` |

## การต่อสาย

ต่อ ESP32 กับ BU01 เหมือนกันทั้ง Node A และ Node B:

| BU01 / DW1000 | ESP32 |
|---|---:|
| SCK | GPIO18 |
| MISO | GPIO19 |
| MOSI | GPIO23 |
| CS / SS | GPIO5 |
| IRQ | GPIO34 |
| RST | GPIO4 |
| GND | GND |
| VCC | 3.3V หรือ VIN ที่ยืนยันจากโมดูลแล้ว |

ขาสัญญาณ DW1000 ต้องใช้ระดับ 3.3V และควรใช้สาย SPI ที่สั้น ห้ามนำจอ ST7789 แบบไม่มี CS มาใช้ SPI bus เดียวกับ DW1000 จอต้องอยู่บน `SPIClass` อีก bus หนึ่ง

## Upload ด้วย PlatformIO

ไฟล์ `platformio.ini` มี environment แยกสองตัว:

- `master`: กำหนด `UWB_IS_MASTER=1`
- `tag`: กำหนด `UWB_IS_MASTER=0`

ชื่อ environment และ macro เป็นชื่อเดิมของ test ที่ผ่านการทดสอบแล้ว โดย `master` หมายถึง Node A/Anchor และ `tag` หมายถึง Node B/Tag

Build ทั้งสอง role:

```powershell
& "$env:USERPROFILE\.platformio\penv\Scripts\platformio.exe" run -d firmware\tests\uwb_pair_test -e master -e tag
```

Upload Node A/Anchor โดยเปลี่ยน `COM_NODE_A` เป็น port จริง:

```powershell
& "$env:USERPROFILE\.platformio\penv\Scripts\platformio.exe" run -d firmware\tests\uwb_pair_test -e master -t upload --upload-port COM_NODE_A
```

Upload Node B/Tag โดยเปลี่ยน `COM_NODE_B` เป็น port จริง:

```powershell
& "$env:USERPROFILE\.platformio\penv\Scripts\platformio.exe" run -d firmware\tests\uwb_pair_test -e tag -t upload --upload-port COM_NODE_B
```

## Upload ด้วย Arduino IDE

1. Copy folder `lib/DW1000` ไปที่ `Documents\Arduino\libraries\DW1000`
2. Restart Arduino IDE
3. เปิด `arduino/uwb_pair_test_arduino/uwb_pair_test_arduino.ino`
4. เลือกบอร์ด `ESP32 Dev Module` และ COM port ของ Node A
5. ตั้ง `#define UWB_IS_MASTER 1` แล้ว Upload ลง Node A
6. เปลี่ยนเป็น `#define UWB_IS_MASTER 0`
7. เลือก COM port ของ Node B แล้ว Upload
8. เปิด Serial Monitor ที่ `115200`

## วิธีทดสอบ

1. เปิด Node A และ Node B โดยวางห่างกันประมาณ 1 เมตรและหันเสาอากาศในแนวเดียวกัน
2. ตรวจ Serial Monitor ของ Node A ว่ามี `Role: MASTER / ANCHOR` ซึ่งเป็นข้อความเดิมของ diagnostic firmware
3. ตรวจ Serial Monitor ของ Node B ว่ามี `Role: SLAVE 1 / TAG` ซึ่งเป็นข้อความเดิมของ diagnostic firmware
4. รอข้อความ `UWB peer connected`
5. ตรวจว่ามีข้อความ `Range #...` ต่อเนื่อง
6. เชื่อมต่อโทรศัพท์หรือคอมพิวเตอร์กับ Wi-Fi `S.T.A.T-UWB`
7. ใส่รหัสผ่าน `statuwb123`
8. เปิด `http://192.168.4.1`
9. ตรวจว่า distance, RX power, quality และ range updates เปลี่ยนตาม Serial Monitor
10. ทดสอบซ้ำที่ระยะจริง 1 m, 2 m, 5 m และ 10 m

ตัวอย่าง Serial output:

```text
S.T.A.T real UWB pair ranging test
Role: MASTER / ANCHOR
Wi-Fi AP: S.T.A.T-UWB
Password: statuwb123
Monitor: http://192.168.4.1
UWB peer connected: short address 0x751C
Range #1: 1.02 m, RX -76.4 dBm, quality 8.0
```

## การบันทึกผล

บันทึกผลแต่ละระยะลง `test-logs/uwb-pair-test.md` โดยใช้ตารางนี้:

| Pair | ระยะจริง (m) | ระยะเฉลี่ย (m) | Error (m) | RX power (dBm) | Quality | หมายเหตุ |
|---|---:|---:|---:|---:|---:|---|
| Node A-Node B | 1 | | | | | |
| Node A-Node B | 2 | | | | | |
| Node A-Node B | 5 | | | | | |
| Node A-Node B | 10 | | | | | |

คำนวณ error ด้วยสูตร:

```text
Error = ระยะเฉลี่ยที่วัดได้ - ระยะจริง
```

## Troubleshooting

### ไม่พบ UWB peer

- ตรวจ VCC และ GND ของทั้งสอง node
- ตรวจ SCK, MISO, MOSI, CS, IRQ และ RST
- ตรวจว่า Node A ใช้ Anchor build และ Node B ใช้ Tag build
- ตรวจว่าทั้งสองตัวใช้ mode และ library รุ่นเดียวกัน
- ลดระยะเหลือประมาณ 0.5-1 เมตรเพื่อเริ่มทดสอบ

### มี peer แต่ไม่มีค่า Range

- ใช้แหล่งจ่ายไฟที่นิ่งและสาย USB ที่จ่ายกระแสได้พอ
- ใช้สาย SPI ให้สั้น
- กด Reset ทั้งสอง node หลัง Upload
- ตรวจ Serial Monitor ที่ `115200`

### เข้าเว็บไม่ได้

- ตรวจว่าเชื่อมต่อ Wi-Fi `S.T.A.T-UWB` ไม่ใช่ Wi-Fi อื่น
- เปิด `http://192.168.4.1` โดยใช้ `http` ไม่ใช่ `https`
- ตรวจ Serial Monitor ของ Node A/Anchor ว่าแสดง IP address
- ปิด mobile data ชั่วคราวถ้าโทรศัพท์พยายามสลับออกจาก Wi-Fi ที่ไม่มีอินเทอร์เน็ต

### ระยะคลาดเคลื่อนมาก

- วางโมดูลให้อยู่นิ่งและเสาอากาศอยู่ในแนวเดียวกัน
- หลีกเลี่ยงโลหะ กำแพง และร่างกายที่บังเส้นทางสัญญาณ
- เก็บ raw range หลาย sample ที่ระยะจริง 1 m, 2 m และ 5 m โดยปิด range filter
- ปรับ `UWB_ANTENNA_DELAY` หลังยืนยันว่า error เป็น systematic bias
- เปิด range filter กลับหลัง calibration ผ่านแล้วเท่านั้น

## เกณฑ์ผ่านขั้นแรก

- Node A และ Node B พบกันต่อเนื่อง
- Serial Monitor แสดงค่าระยะจริงโดยไม่ใช่ mock data
- เว็บมอนิเตอร์แสดงข้อมูลเดียวกับ Serial Monitor
- ทดสอบ 1 m, 2 m, 5 m และ 10 m พร้อมบันทึก error, RX power และ quality

ผล calibration ปัจจุบันถูกบันทึกไว้ใน `test-logs/uwb-pair-test.md` ขั้นต่อไปคือยืนยัน ranging เดิมหลังติดตั้ง ST7789, GY-511 และ MAX30102 ครบทั้งสอง node ก่อน integrate production Radar firmware

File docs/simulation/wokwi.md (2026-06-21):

# Wokwi Simulation Status

The checked-in `firmware/sim/wokwi` project predates the two-node Radar pivot. It demonstrates the superseded three-node triangle UI with mocked values and is not validation of the current Radar MVP.

## Current Use

The old simulation may still be used to inspect:

- ESP32 display rendering through Wokwi's ILI9341 visual surrogate
- Basic SPI display behavior
- Historical triangle-map UI behavior

Do not use it to validate current Node A/B data flow, movement-bearing estimation, ESP-NOW, reciprocal bearing, or auto-range behavior.

## Current Hardware Display

Real hardware uses a no-CS ZJY-IPS130-V2.0 ST7789 240x240 display:

- Module `SCL` is SPI SCK.
- Module `SDA` is SPI MOSI.
- `BLC` controls the backlight.
- `DC` selects command/data.
- `RES` resets the display.
- The display runs on dedicated HSPI and does not share the DW1000 default SPI bus.
- The physical panel requires a manual reset pulse, `SPI_MODE3`, and 8 MHz display transactions; the ILI9341 surrogate does not validate this hardware-specific contract.

Wokwi does not provide a built-in ST7789 part matching this module, so the ILI9341 may remain a visual surrogate in a future Radar simulation.

## Replacement Simulation Requirements

A current simulation must model one Radar Node screen with controllable inputs for:

- UWB distance
- Compass heading
- Forward/right acceleration
- Peer BPM validity and value
- UWB and ESP-NOW link states

It must show the north-up radar, movement-bearing response, automatic `5/10/20/40m` scale, retained UWB-lost dot, and stale Peer BPM behavior.

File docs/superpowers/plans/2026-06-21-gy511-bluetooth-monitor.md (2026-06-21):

# GY-511 Bluetooth Monitor Implementation Plan

> **For agentic workers:** REQUIRED SUB-SKILL: Use superpowers:subagent-driven-development (recommended) or superpowers:executing-plans to implement this plan task-by-task. Steps use checkbox (`- [ ]`) syntax for tracking.

**Goal:** Mirror the GY-511 diagnostic output to Bluetooth Classic SPP while retaining USB Serial output and sensor operation when Bluetooth initialization fails.

**Architecture:** Keep the change inside the existing GY-511 test sketch. Add one Bluetooth transport and small line-output helpers so every diagnostic message reaches USB and, when available, Bluetooth without changing sensor register access.

**Tech Stack:** Arduino-ESP32, `BluetoothSerial`, PlatformIO, PowerShell regression check

---

### Task 1: Define the Bluetooth logging contract

**Files:**
- Create: `tools/verify-gy511-bluetooth.ps1`
- Test: `firmware/tests/gy511_test/src/main.cpp`

- [x] **Step 1: Write the failing source regression check**

Create a PowerShell script that verifies the sketch includes `BluetoothSerial.h`, enables SSP before starting `BPMWATCH-GY511`, omits legacy PIN configuration, and routes complete status and sample lines through a shared dual-output helper.

- [x] **Step 2: Run the check to verify it fails**

Run: `powershell -ExecutionPolicy Bypass -File tools/verify-gy511-bluetooth.ps1`

Expected: non-zero exit with a missing Bluetooth contract assertion.

### Task 2: Implement dual USB and Bluetooth output

**Files:**
- Modify: `firmware/tests/gy511_test/src/main.cpp`

- [x] **Step 1: Add minimal Bluetooth setup and output helpers**

Add `BluetoothSerial SerialBT`, a `bluetoothReady` state, and helpers that send each complete diagnostic line to USB and to SPP only when startup succeeded. Enable SSP before starting the device as `BPMWATCH-GY511`, and continue GY-511 initialization on Bluetooth failure.

- [x] **Step 2: Route existing status, errors, and sensor readings through the helper**

Format the existing sensor sample into a fixed local buffer and preserve the current fields, heading precision, and 500 ms interval.

- [x] **Step 3: Run the regression check**

Run: `powershell -ExecutionPolicy Bypass -File tools/verify-gy511-bluetooth.ps1`

Expected: `PASS: GY-511 Bluetooth diagnostic contract verified.`

### Task 3: Compile verification

**Files:**
- Verify: `firmware/tests/gy511_test/platformio.ini`

- [x] **Step 1: Build the GY-511 test environment**

Run: `C:\Users\pipat\.platformio\penv\Scripts\platformio.exe run -d firmware/tests/gy511_test`

Expected: `SUCCESS` for `esp32dev` with no compiler errors.

- [x] **Step 2: Review only task-owned changes**

Run: `git diff --check -- firmware/tests/gy511_test/src/main.cpp tools/verify-gy511-bluetooth.ps1 docs/superpowers/plans/2026-06-21-gy511-bluetooth-monitor.md`

Expected: no whitespace errors. Do not stage or alter unrelated worktree changes.

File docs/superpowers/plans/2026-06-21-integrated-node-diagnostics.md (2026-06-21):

# Integrated Node Diagnostics Implementation Plan

> **For agentic workers:** REQUIRED SUB-SKILL: Use superpowers:subagent-driven-development (recommended) or superpowers:executing-plans to implement this plan task-by-task. Steps use checkbox (`- [ ]`) syntax for tracking.

**Goal:** Build a two-environment hardware integration test that continuously ranges with DW1000, samples GY-511 and MAX30102, and displays live diagnostics on the ST7789.

**Architecture:** A shared `DiagnosticsState` is written by three focused hardware modules and read by a display module. `main.cpp` owns one non-blocking scheduler; the default SPI bus belongs to DW1000, dedicated HSPI belongs to the no-CS display, and I2C is initialized once for both sensors.

**Tech Stack:** Arduino-ESP32 3.3.5, PlatformIO, vendored DW1000 library, SparkFun MAX3010x, Adafruit GFX/ST7789, PowerShell source checks, PlatformIO native tests

---

### Task 1: Add Failing Integration Contracts

**Files:**
- Create: `tools/verify-integrated-node-test.ps1`
- Create: `firmware/tests/integrated_node_test/test/test_median_range_filter.cpp`

- [ ] **Step 1: Write the failing source contract**

The PowerShell check must require both environments, the expected source modules, Node A/Node B roles, one `Wire.begin(21, 22)`, the confirmed ST7789 sequence, continuous UWB polling, 20/50/200/1000 ms scheduler intervals, and absence of `BluetoothSerial.h`, BLE, `WebServer.h`, `WiFi.h`, `softAP`, and `delay(20)`. It exits non-zero and prints every missing contract.

- [ ] **Step 2: Write the median filter native test**

Copy the proven assertions from `firmware/tests/uwb_pair_test/test/test_median_range_filter.cpp` and point the include at `../src/MedianRangeFilter.h`. The test covers invalid range rejection, a single outlier, and a real 10 m to 20 m step.

- [ ] **Step 3: Verify RED**

Run:

```powershell
powershell -ExecutionPolicy Bypass -File tools/verify-integrated-node-test.ps1
```

Expected: FAIL because `firmware/tests/integrated_node_test` does not exist.

### Task 2: Create Shared Configuration And State

**Files:**
- Create: `firmware/tests/integrated_node_test/platformio.ini`
- Create: `firmware/tests/integrated_node_test/src/NodeConfig.h`
- Create: `firmware/tests/integrated_node_test/src/DiagnosticsState.h`
- Create: `firmware/tests/integrated_node_test/src/MedianRangeFilter.h`

- [ ] **Step 1: Define both build environments**

Use a shared environment with `lib_extra_dirs = ../../../lib` and these dependencies:

```ini
lib_deps =
  sparkfun/SparkFun MAX3010x Pulse and Proximity Sensor Library
  adafruit/Adafruit GFX Library
  adafruit/Adafruit ST7735 and ST7789 Library
```

Set `BPMWATCH_NODE_ID=0` for `node_a_anchor` and `BPMWATCH_NODE_ID=1` for `node_b_tag`. Both use antenna delay `16555`, discovery recovery `5000`, and connected recovery `15000`.

Add a separate `[env:native]` using `platform = native` for the header-only median filter test; it does not compile Arduino sources.

- [ ] **Step 2: Define compile-time node identity**

`NodeConfig.h` exposes:

```cpp
struct NodeConfig {
  uint8_t nodeId;
  bool isAnchor;
  const char* displayLabel;
  const char* uwbEui;
};

inline constexpr NodeConfig kNodeConfig = /* selected by BPMWATCH_NODE_ID */;
```

Node A uses `NODE A / ANCHOR` and `0C:8A:D3:7C:E5:A4:00:01`; Node B uses `NODE B / TAG` and `1C:75:C4:F4:E9:D4:00:01`.

- [ ] **Step 3: Define shared state**

Create `UwbDiagnosticState`, `Gy511DiagnosticState`, `Max30102DiagnosticState`, and aggregate `DiagnosticsState`. Include readiness/error flags, range freshness fields, heading/accel, IR/finger/BPM, and initialize values to safe zero/false defaults.

- [ ] **Step 4: Copy the proven median filter**

Copy `MedianRangeFilter` unchanged from `firmware/tests/uwb_pair_test/src/MedianRangeFilter.h` so the native test verifies exactly the bench-tested behavior.

- [ ] **Step 5: Run the native test**

Run:

```powershell
C:\Users\pipat\.platformio\penv\Scripts\platformio.exe test -d firmware/tests/integrated_node_test -e native
```

Expected: all three median-filter assertions pass.

### Task 3: Implement Both I2C Sensor Modules

**Files:**
- Create: `firmware/tests/integrated_node_test/src/Gy511Sensor.h`
- Create: `firmware/tests/integrated_node_test/src/Gy511Sensor.cpp`
- Create: `firmware/tests/integrated_node_test/src/Max30102Sensor.h`
- Create: `firmware/tests/integrated_node_test/src/Max30102Sensor.cpp`

- [ ] **Step 1: Implement GY-511 without owning `Wire.begin()`**

Expose:

```cpp
class Gy511Sensor {
 public:
  bool begin(TwoWire& wire);
  void sample(Gy511DiagnosticState& state);
};
```

Reuse addresses `0x19`/`0x1E`, confirmed register values, byte ordering, and normalized `atan2f(my, mx)` heading from `gy511_test`. A failed read sets `readOk=false` and preserves process liveness.

- [ ] **Step 2: Implement MAX30102 without blocking**

Expose:

```cpp
class Max30102Sensor {
 public:
  bool begin(TwoWire& wire);
  void sample(uint32_t nowMs, Max30102DiagnosticState& state);
};
```

Reuse the current MAX30102 LED setup, `checkForBeat`, 40-220 BPM validation, four-value average, and `IR >= 50000` finger threshold. Do not call `delay()`.

- [ ] **Step 3: Compile-check both modules through the full environments**

Run both `node_a_anchor` and `node_b_tag` builds after `main.cpp` is available in Task 6; until then use the source contract to verify neither module calls `Wire.begin()` or `delay(20)`.

### Task 4: Implement UWB Diagnostics

**Files:**
- Create: `firmware/tests/integrated_node_test/src/UwbDiagnostics.h`
- Create: `firmware/tests/integrated_node_test/src/UwbDiagnostics.cpp`

- [ ] **Step 1: Define the callback-owning module**

Expose:

```cpp
class UwbDiagnostics {
 public:
  void begin(UwbDiagnosticState& state);
  void poll(uint32_t nowMs, UwbDiagnosticState& state);
 private:
  void restart(UwbDiagnosticState& state);
};
```

Use a single static instance/state bridge for the C-style `DW1000Ranging` callbacks.

- [ ] **Step 2: Port proven pair ranging without network code**

Keep pins `18/19/23/5/34/4`, antenna delay `16555`, `MODE_LONGDATA_RANGE_ACCURACY`, five-sample median filtering, printable `DECA` identifier check, range/RX/quality callbacks, device/inactive callbacks, Anchor blink callback, and current 5 s/15 s Anchor recovery behavior. Do not include Wi-Fi or webserver code.

- [ ] **Step 3: Expose display-safe state**

Update filtered distance and `lastRangeMs` only for accepted samples. Mark a range lost when its age exceeds 3000 ms while preserving the last distance.

### Task 5: Implement The ST7789 Dashboard

**Files:**
- Create: `firmware/tests/integrated_node_test/src/DiagnosticsDisplay.h`
- Create: `firmware/tests/integrated_node_test/src/DiagnosticsDisplay.cpp`

- [ ] **Step 1: Implement confirmed display initialization**

Own `SPIClass(HSPI)` and `Adafruit_ST7789` with no CS. Use pins `14/13/25/26/27`, manual reset holds, `init(240, 240, SPI_MODE3)`, and `setSPISpeed(8000000)` after init.

- [ ] **Step 2: Draw a fixed dashboard**

Draw the Node/role header and three bordered panels once. Provide `render(const DiagnosticsState&, uint32_t nowMs)` that clears only panel value rectangles and uses green for valid, orange for wait/no-finger, and red for errors.

- [ ] **Step 3: Render required values**

UWB shows state and filtered distance; GY-511 shows state, heading, and accel X/Y/Z; MAX30102 shows state, IR, and averaged BPM. Use `--` for unavailable values and preserve the last distance with `LOST` after 3 seconds.

### Task 6: Integrate The Non-Blocking Scheduler

**Files:**
- Create: `firmware/tests/integrated_node_test/src/main.cpp`

- [ ] **Step 1: Initialize buses and modules in ownership order**

Initialize Serial, call `Wire.begin(21, 22)` once, initialize the display, both I2C modules, then UWB/default SPI. Each init result updates only its module state.

- [ ] **Step 2: Implement elapsed-time scheduling**

The loop must:

```cpp
uwb.poll(nowMs, state.uwb);                    // every pass
if (nowMs - lastMaxMs >= 20) { max30102.sample(nowMs, state.max30102); }
if (nowMs - lastGyMs >= 50) { gy511.sample(state.gy511); }
if (nowMs - lastDisplayMs >= 200) { display.render(state, nowMs); }
if (nowMs - lastLogMs >= 1000) { logDiagnostics(state, nowMs); }
```

There is no Bluetooth, Wi-Fi, webserver, mock data, or blocking sensor delay.

- [ ] **Step 3: Verify GREEN source contract**

Run:

```powershell
powershell -ExecutionPolicy Bypass -File tools/verify-integrated-node-test.ps1
```

Expected: `PASS: integrated node diagnostics contract verified.`

### Task 7: Build And Review

**Files:**
- Verify: `firmware/tests/integrated_node_test/**`
- Verify: `tools/verify-integrated-node-test.ps1`

- [ ] **Step 1: Run the native median-filter test**

```powershell
C:\Users\pipat\.platformio\penv\Scripts\platformio.exe test -d firmware/tests/integrated_node_test -e native
```

Expected: PASS.

- [ ] **Step 2: Build Node A**

```powershell
C:\Users\pipat\.platformio\penv\Scripts\platformio.exe run -d firmware/tests/integrated_node_test -e node_a_anchor
```

Expected: SUCCESS.

- [ ] **Step 3: Build Node B**

```powershell
C:\Users\pipat\.platformio\penv\Scripts\platformio.exe run -d firmware/tests/integrated_node_test -e node_b_tag
```

Expected: SUCCESS.

- [ ] **Step 4: Review task-owned changes**

Run `git diff --check` and inspect only the new integrated test, verifier, and this plan. Do not stage or alter unrelated existing worktree changes.

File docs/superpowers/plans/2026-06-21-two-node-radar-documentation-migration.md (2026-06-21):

# Two-Node Radar Documentation Migration Implementation Plan

> **For agentic workers:** REQUIRED SUB-SKILL: Use superpowers:subagent-driven-development (recommended) or superpowers:executing-plans to implement this plan task-by-task. Steps use checkbox (`- [ ]`) syntax for tracking.

**Goal:** Make every first-party project document describe the approved two-node Radar MVP while preserving the superseded three-node material as clearly marked legacy history.

**Architecture:** Current documentation uses Node A and Node B as equal Radar Nodes, with fixed DW1000 Anchor/Tag radio roles, UWB distance, GY-511 movement-bearing estimation, ESP-NOW Peer BPM/bearing exchange, and ST7789 radar output. Three-node triangle documents and diagrams move under `docs/legacy/three-node/`; diagnostic UWB pair guides remain in place because their AP monitor and legacy build labels are still useful test tooling.

**Tech Stack:** Markdown, SVG, PlatformIO project paths, PowerShell verification, Git

**Execution Status:** Completed on 2026-06-21; checkboxes below preserve the original execution sequence.

---

### Task 1: Preserve Superseded Three-Node Documents

**Files:**
- Move: `relative_2d_map_architecture.svg` to `docs/legacy/three-node/relative_2d_map_architecture.svg`
- Move: `docs/relative-2d-map.md` to `docs/legacy/three-node/relative-2d-map.md`
- Move: `test-logs/uwb-triangle-test.md` to `docs/legacy/three-node/test-logs/uwb-triangle-test.md`
- Create: `docs/legacy/three-node/README.md`

- [ ] **Step 1: Create the legacy index**

Document that the folder contains the superseded one-Master/two-Slave triangle architecture and that it must not be used for current firmware decisions.

- [ ] **Step 2: Move the historical files without changing their evidence**

Use `apply_patch` moves so Git retains history and no historical content is discarded.

- [ ] **Step 3: Verify legacy isolation**

```powershell
rg -n "TeamMapPacket|Slave 2|triangle" docs/legacy/three-node
```

Expected: matches occur only in the legacy folder and are described as superseded.

### Task 2: Rewrite Current Architecture and Planning Documents

**Files:**
- Modify: `README.md`
- Modify: `BPMWATCH_PROJECT_PLAN_AND_REPO_PROMPT.md`
- Modify: `docs/architecture.md`
- Modify: `docs/ranging-protocol.md`
- Modify: `docs/limitations.md`
- Modify: `docs/simulation/wokwi.md`
- Modify: `hardware/diagrams/README.md`

- [ ] **Step 1: Rewrite the root README**

Describe two equal Radar Nodes, the fixed radio roles, the two data links, the new production path, current diagnostic status, build commands, and links to the approved spec and SVG.

- [ ] **Step 2: Replace the old project plan**

Use the approved MVP phases: documentation migration, common hardware bring-up, production firmware, radar estimation, ESP-NOW Peer data, bench verification, and field/power validation.

- [ ] **Step 3: Rewrite architecture and protocol documents**

Define UWB as distance-only and ESP-NOW as Peer BPM plus reciprocal-bearing transport. Explicitly state that Anchor/Tag does not imply application Master/Slave.

- [ ] **Step 4: Mark the current Wokwi simulation as legacy**

State that `firmware/sim/wokwi` still demonstrates the old triangle UI and is not proof of the Radar MVP until replaced.

### Task 3: Align Hardware Documents

**Files:**
- Modify: `docs/bom.md`
- Modify: `docs/pin-map.md`
- Create: `docs/wiring-node-a.md`
- Create: `docs/wiring-node-b.md`
- Move: `docs/wiring-master.md` to `docs/legacy/three-node/wiring-master.md`
- Move: `docs/wiring-slave.md` to `docs/legacy/three-node/wiring-slave.md`
- Modify: `hardware/case/README.md`
- Modify: `hardware/photos/README.md`
- Modify: `hardware/kicad/bpmwatch/README.md`
- Modify: `hardware/kicad/bpmwatch/FOOTPRINT_RESEARCH.md`

- [ ] **Step 1: Make Node A and Node B hardware-equivalent**

List two each of ESP32, BU01, ST7789, GY-511, MAX30102, battery, charger, regulator, and enclosure hardware.

- [ ] **Step 2: Lock the confirmed bus pins**

Record DW1000 default SPI, ST7789 dedicated HSPI, and shared I2C GPIO21/22 for both nodes.

- [ ] **Step 3: Add role-specific wiring pages**

Node A and Node B use identical wiring; only MAC and fixed DW1000 radio role differ.

- [ ] **Step 4: Mark the current KiCad schematic as pre-pivot**

Do not claim the old Master/repeated-Slave schematic is current. Record that it must be regenerated for two equivalent Radar Nodes before production use.

### Task 4: Align Diagnostic UWB Guides

**Files:**
- Modify: `docs/arduino-ide-uwb-pair-test.md`
- Modify: `docs/arduino-ide-uwb-pair-test-th.md`
- Modify: `docs/uwb-pair-ranging-ap-implementation-th.md`

- [ ] **Step 1: Add a diagnostic-only architecture notice**

Explain that AP/webserver behavior belongs only to `uwb_pair_test`, not production Radar firmware.

- [ ] **Step 2: Map legacy build labels to current node names**

Document `master`/`UWB_IS_MASTER=1` as Node A/Anchor and `tag`/`UWB_IS_MASTER=0` as Node B/Tag. Preserve literal output examples where the existing test still prints legacy labels.

- [ ] **Step 3: Remove obsolete next steps**

Do not direct users to test a third node or triangle ranging after the pair test.

### Task 5: Rewrite Test Plan and Logs

**Files:**
- Modify: `docs/test-plan.md`
- Modify: `test-logs/uwb-pair-test.md`
- Modify: `test-logs/battery-test.md`
- Modify: `test-logs/field-test.md`
- Create: `test-logs/radar-mvp-test.md`

- [ ] **Step 1: Preserve current user-recorded results**

Keep the completed I2C, BPM, charger, GY-511, and UWB measurements. Rename the tested pair from `M-S1` to `Node A-Node B` without altering numeric evidence.

- [ ] **Step 2: Replace triangle/map checks**

Add Node A/B hardware parity, GY-511 axis mapping, motion bearing, reciprocal bearing, UWB lost-dot persistence, ESP-NOW Peer BPM, auto-range, and two-screen radar checks.

- [ ] **Step 3: Add a Radar MVP evidence table**

Capture moving node, distance trend, expected/observed bearing, both screen states, UWB state, Peer BPM state, range band, and notes.

### Task 6: Align Repository Support Documents

**Files:**
- Modify: `firmware/legacy/README.md`
- Modify: `hardware/diagrams/README.md`
- Modify: `hardware/case/README.md`
- Modify: `hardware/photos/README.md`

- [ ] **Step 1: Point each support folder to the current architecture**

Use `radar_2d_map_architecture.svg`, Node A/B naming, and the two-node hardware contract.

- [ ] **Step 2: Explain code migration timing honestly**

State that `firmware/master` and `firmware/slave` are deprecated and scheduled for legacy relocation during firmware implementation; do not claim they have already moved.

### Task 7: Verify and Commit the Documentation Migration

**Files:**
- Verify: all first-party `*.md` and architecture `*.svg` files outside `docs/legacy/`

- [ ] **Step 1: Scan current docs for forbidden architecture terms**

```powershell
rg -n -i "1 master|2 slave|slave 2|three-node|3-node|TeamMapPacket|triangle map" README.md BPMWATCH_PROJECT_PLAN_AND_REPO_PROMPT.md CONTEXT.md docs hardware test-logs firmware/legacy -g "*.md" -g "!docs/legacy/**"
```

Expected: no current-architecture claims; matches are only explicit legacy/diagnostic notices.

- [ ] **Step 2: Check links and referenced paths**

```powershell
@'
import pathlib, re
root = pathlib.Path('.')
missing = []
for path in root.rglob('*.md'):
    if '.pio' in path.parts or 'lib' in path.parts:
        continue
    text = path.read_text(encoding='utf-8')
    for target in re.findall(r'\[[^]]+\]\(([^)#]+)', text):
        if '://' in target or target.startswith('#'):
            continue
        resolved = (path.parent / target).resolve()
        if not resolved.exists():
            missing.append((str(path), target))
print('\n'.join(f'{p}: {t}' for p, t in missing))
raise SystemExit(1 if missing else 0)
'@ | python -
```

Expected: exit 0 with no missing local links.

- [ ] **Step 3: Validate Markdown/SVG hygiene and staged scope**

```powershell
$svgText = Get-Content -Raw -Encoding UTF8 radar_2d_map_architecture.svg
$svg = [xml]$svgText
git diff --check
git status --short
```

Expected: valid SVG XML, no whitespace errors, and user-owned firmware changes remain unstaged.

- [ ] **Step 4: Commit only documentation migration files**

```powershell
git add -- README.md BPMWATCH_PROJECT_PLAN_AND_REPO_PROMPT.md CONTEXT.md docs hardware test-logs firmware/legacy radar_2d_map_architecture.svg
git diff --cached --check
git commit -m "docs: migrate project to two-node radar architecture"
```

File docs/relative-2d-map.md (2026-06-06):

# Relative 2D Map

The map solver uses 3 measured distances:

- `dM1`: Master to Slave 1
- `dM2`: Master to Slave 2
- `d12`: Slave 1 to Slave 2

## Coordinate Setup

Use a simple reference frame:

```text
Master = (0, 0)
Slave 1 = (dM1, 0)
Slave 2 = (x, y)
```

Compute Slave 2:

```text
x = (dM2^2 + dM1^2 - d12^2) / (2 * dM1)
y = sqrt(dM2^2 - x^2)
```

## Invalid Triangle Handling

The map is invalid when:

- Any distance is zero or negative.
- `dM1` is too small to place Slave 1.
- Triangle inequality fails.
- The square root term becomes negative after noise tolerance.

When invalid, the firmware should keep the last known good map briefly, then show a ranging lost state.

## Noise Smoothing

Start with simple exponential smoothing:

```text
smoothed = previous * 0.7 + measured * 0.3
```

Do not over-smooth during early testing because bad UWB measurements must remain visible.

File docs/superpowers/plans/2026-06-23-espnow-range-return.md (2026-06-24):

# ESP-NOW Range Return Implementation Plan

> **For agentic workers:** REQUIRED SUB-SKILL: Use superpowers:subagent-driven-development (recommended) or superpowers:executing-plans to implement this plan task-by-task. Steps use checkbox (`- [ ]`) syntax for tracking.

**Goal:** Let Node A use the proven UWB Anchor range path and send measured distance back to Node B over ESP-NOW for display/radar rendering.

**Architecture:** Node A remains the UWB Anchor and becomes an ESP-NOW sender. Node B remains the UWB Tag for the DW1000 handshake and becomes an ESP-NOW receiver; its screen uses the latest Node A range packet as the display source. No Wi-Fi AP, WebServer, or browser UI is added.

**Tech Stack:** Arduino ESP32, DW1000Ranging, ESP-NOW, Adafruit ST7789, PlatformIO.

---

### Task 1: Add ESP-NOW Range Packet Module

**Files:**
- Create: `firmware/tests/integrated_node_test/src/EspNowRangeLink.h`
- Create: `firmware/tests/integrated_node_test/src/EspNowRangeLink.cpp`
- Test: `firmware/tests/integrated_node_test/test/test_espnow_range_packet.cpp`

- [x] **Step 1: Define a compact range packet with magic/version validation**

Create a packet containing sequence, distance, raw distance, RX power, quality, range count, and sender timestamp. Add native-testable validation helpers that reject wrong magic/version/size.

- [x] **Step 2: Implement ESP-NOW sender/receiver wrappers**

Use `WiFi.mode(WIFI_STA)`, `esp_now_init()`, and a fixed Node B STA MAC peer for Node A. On Node B, register a receive callback and update `UwbDiagnosticState` from valid packets.

### Task 2: Add ESP-NOW Build Environments

**Files:**
- Modify: `firmware/tests/integrated_node_test/platformio.ini`
- Modify: `tools/verify-integrated-node-test.ps1`

- [x] **Step 1: Add `node_a_anchor_espnow_range` and `node_b_tag_espnow_display`**

These envs use the same integrated firmware with `BPMWATCH_ESPNOW_RANGE_LINK=true`.

- [x] **Step 2: Update verification contract**

Require the new envs and ESP-NOW module, allow `WiFi.h` only for ESP-NOW while still forbidding `WebServer.h` and `softAP`.

### Task 3: Wire ESP-NOW Into Runtime

**Files:**
- Modify: `firmware/tests/integrated_node_test/src/UwbDiagnostics.cpp`
- Modify: `firmware/tests/integrated_node_test/src/main.cpp`
- Modify: `firmware/tests/integrated_node_test/src/DiagnosticsState.h`

- [x] **Step 1: Match pair-test recovery behavior**

Keep app-level UWB recovery on Node A/Anchor. Disable app-level recovery on Node B/Tag unless explicitly enabled by a build flag.

- [x] **Step 2: Send Node A range updates**

When `rangeCount` increases on Node A, send the latest range state over ESP-NOW.

- [x] **Step 3: Receive Node B display updates**

When Node B receives a valid ESP-NOW range packet, update `state.uwb` and let the existing radar/display path render it.

### Task 4: Verify

**Files:**
- Run: `tools/verify-integrated-node-test.ps1`
- Run: PlatformIO native tests
- Build: ESP-NOW Node A and Node B envs

- [x] **Step 1: Run native/unit checks**

Expected: packet helper tests and existing radar/GY/filter tests pass.

- [x] **Step 2: Build both uploadable ESP-NOW envs**

Expected: `node_a_anchor_espnow_range` and `node_b_tag_espnow_display` build successfully.

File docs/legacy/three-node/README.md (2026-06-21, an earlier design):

# Legacy Three-Node Architecture

This folder preserves the superseded BPMWATCH architecture that used one application Master, two Slaves, three UWB distance pairs, a triangle solver, and `TeamMapPacket` broadcasting.

Do not use these files as the source of truth for current hardware or firmware. The current product is the two-node Radar MVP defined in:

- [`CONTEXT.md`](../../../CONTEXT.md)
- [`README.md`](../../../README.md)
- [`radar_2d_map_architecture.svg`](../../../radar_2d_map_architecture.svg)
- [Radar MVP design spec](../../superpowers/specs/2026-06-21-radar-2d-map-mvp-design.md)

The files here remain useful for understanding earlier experiments and Git history.

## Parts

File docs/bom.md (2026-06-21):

# Two-Node Radar Bill of Materials

Node A and Node B use the same hardware. Quantities below are for the complete two-node MVP.

| Component | Requirement | Qty |
|---|---|---:|
| ESP32-WROOM-32 board | 3.3V logic, Wi-Fi/ESP-NOW, 4MB flash or more | 2 |
| B&T BU01 DW1000 LDO breakout | SPI interface, confirmed power-input pin, 3.3V-safe signals | 2 |
| ZJY-IPS130-V2.0 IPS TFT LCD 240x240 ST7789 | No-CS module exposing SCL/SCK, SDA/MOSI, BLC, DC, RES; requires `SPI_MODE3` | 2 |
| GY-511 / LSM303DLHC | I2C accelerometer and compass, addresses `0x19` and `0x1E` | 2 |
| MAX30102 breakout | I2C heart-rate sensor, address `0x57` | 2 |
| 602030 Li-Po battery | 3.7V cell; verify actual capacity and discharge rating | 2 |
| TP4056 Type-C charger | Include battery protection | 2 |
| TPS63802 buck-boost module | Stable 3.3V rail for ESP32, UWB, display, and sensors | 2 |
| Power switch | Rated for the battery path | 2 |
| Bulk and local capacitors | Bulk rail support plus 10uF/0.1uF near active modules | 2 sets |
| SOS/interaction button | Optional for later interaction; not required by Radar MVP UI | 2 |
| Watch strap | Velcro or equivalent wearable strap | 2 |
| Enclosure | 3D-printed or ABS, with antenna and sensor clearances | 2 |

## Node Assignment

| Hardware | Node A / Anchor | Node B / Tag |
|---|---:|---:|
| ESP32 + BU01 | 1 | 1 |
| ST7789 | 1 | 1 |
| GY-511 | 1 | 1 |
| MAX30102 | 1 | 1 |
| Battery power chain | 1 | 1 |

The former third ESP32/BU01 can remain a spare or diagnostic board. It is not part of the current product architecture.

## Purchase Priorities

1. Complete Node A with the ST7789, GY-511, and MAX30102 already used by Node B.
2. Verify the exact BU01 power pin and antenna orientation on both modules.
3. Verify TPS63802 stability during concurrent UWB and ESP-NOW activity.
4. Confirm the exact display header count and physical dimensions before enclosure or PCB work.
5. Defer vibration and waterproofing until the two-screen Radar MVP passes bench testing.

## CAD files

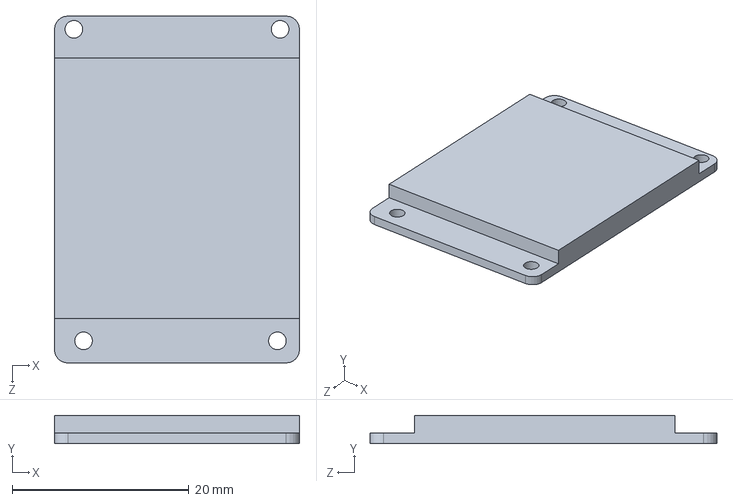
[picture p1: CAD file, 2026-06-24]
hardware/case/LCD.SLDPRT
27.7 x 3.20 x 39.2 mm

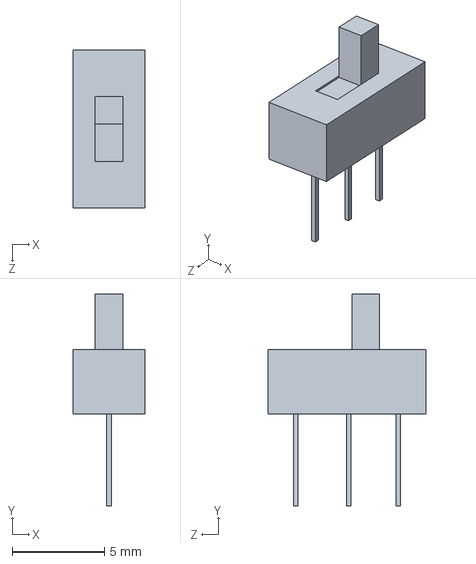
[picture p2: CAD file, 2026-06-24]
hardware/case/switch small.SLDPRT
3.90 x 11.5 x 8.55 mm

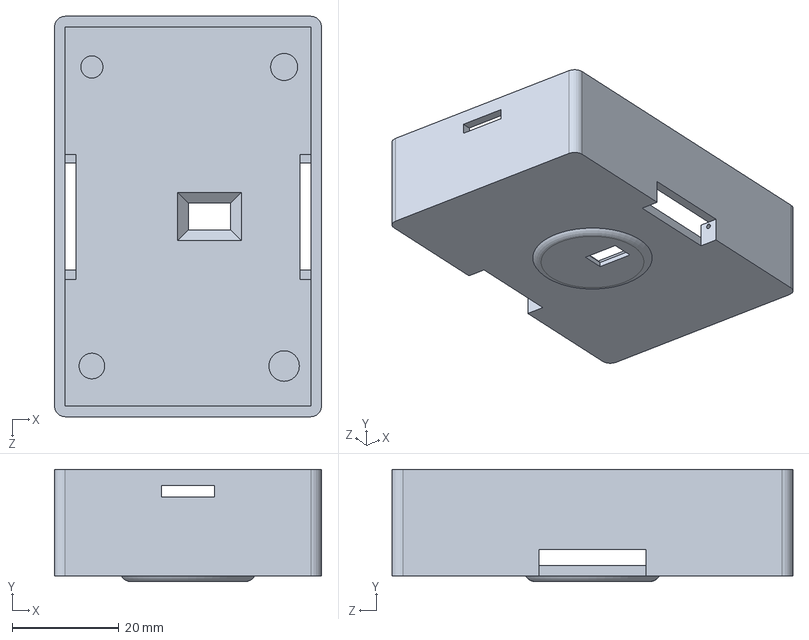
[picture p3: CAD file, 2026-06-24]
hardware/case/casse.SLDPRT
50.0 x 21.0 x 75.0 mm

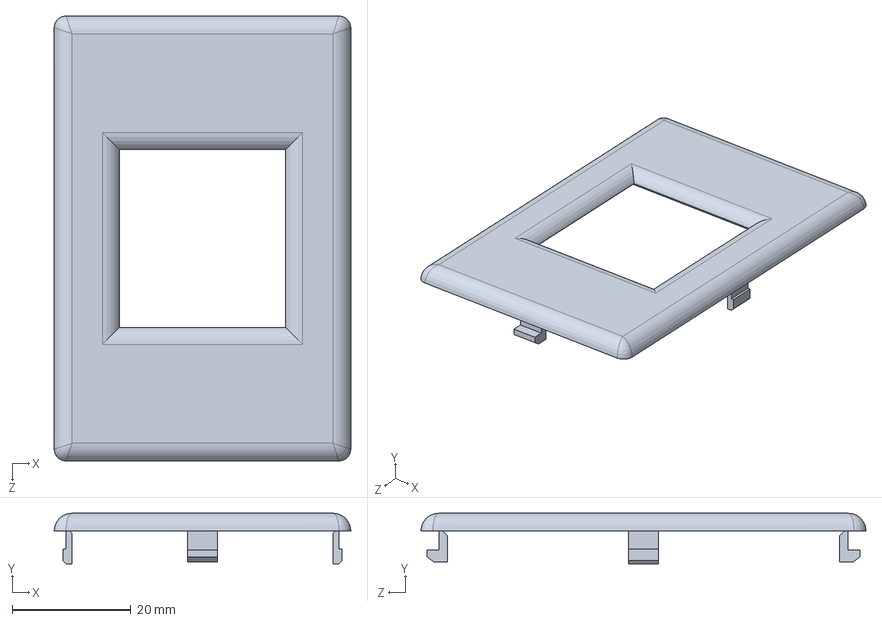
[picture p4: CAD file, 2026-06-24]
hardware/case/cover.SLDPRT
50.0 x 8.53 x 75.0 mm

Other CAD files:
hardware/case/casse.STL
hardware/case/cover.STL

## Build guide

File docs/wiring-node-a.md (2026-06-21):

# Node A Wiring

Node A is an equal Radar Node with the fixed DW1000 Anchor radio role. Its ESP32 STA MAC is `0C:8A:D3:7C:E5:A4`.

## Modules

Node A must contain ESP32, BU01/DW1000, no-CS ZJY-IPS130-V2.0 ST7789, GY-511, MAX30102, and the protected battery power chain. This adds the display and sensors that were absent from the former Master hardware definition.

## Signal Wiring

| Module signal | ESP32 pin |
|---|---:|
| BU01 SCK / MISO / MOSI | GPIO18 / GPIO19 / GPIO23 |
| BU01 CS / IRQ / RST | GPIO5 / GPIO34 / GPIO4 |
| ST7789 SCL / SDA | GPIO14 / GPIO13 |
| ST7789 BLC / DC / RES | GPIO25 / GPIO26 / GPIO27 |
| GY-511 SDA / SCL | GPIO21 / GPIO22 |
| MAX30102 SDA / SCL | GPIO21 / GPIO22 |

The ST7789 labels `SCL` and `SDA` mean SPI SCK and MOSI on this display. They are not I2C.

The confirmed display startup sequence is RES high/low/high, `tft.init(240, 240, SPI_MODE3)`, then `tft.setSPISpeed(8000000)`. Default `SPI_MODE0` did not light the tested ZJY-IPS130-V2.0 panel.

## Power

```text
602030 Li-Po -> protected TP4056 -> power switch -> TPS63802 3.3V
                                                        |
                         ESP32 + BU01 + ST7789 + GY-511 + MAX30102
```

- Share ground across every module.
- Add bulk capacitance at the regulator output.
- Add local 10uF and 0.1uF decoupling near active modules.
- Keep UWB and ESP32 antenna areas clear of battery, display cable, and metal.
- Confirm the exact BU01 breakout power-input label; do not infer 5V tolerance from the `LDO` name.

## Mounting

Mount GY-511 flat and record its X/Y direction relative to the display top. Firmware axis mapping will be validated on the bench before the enclosure orientation is fixed.

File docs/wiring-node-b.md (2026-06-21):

# Node B Wiring

Node B is an equal Radar Node with the fixed DW1000 Tag radio role. Its ESP32 STA MAC is `1C:75:C4:F4:E9:D4`.

## Modules

Node B contains ESP32, BU01/DW1000, no-CS ZJY-IPS130-V2.0 ST7789, GY-511, MAX30102, and the protected battery power chain.

## Signal Wiring

| Module signal | ESP32 pin |
|---|---:|
| BU01 SCK / MISO / MOSI | GPIO18 / GPIO19 / GPIO23 |
| BU01 CS / IRQ / RST | GPIO5 / GPIO34 / GPIO4 |
| ST7789 SCL / SDA | GPIO14 / GPIO13 |
| ST7789 BLC / DC / RES | GPIO25 / GPIO26 / GPIO27 |
| GY-511 SDA / SCL | GPIO21 / GPIO22 |
| MAX30102 SDA / SCL | GPIO21 / GPIO22 |

The no-CS ST7789 uses dedicated HSPI. Initialize the tested ZJY-IPS130-V2.0 with a manual RES pulse, `SPI_MODE3`, and 8 MHz transactions. GY-511 and MAX30102 share I2C GPIO21/22.

## Power

```text
602030 Li-Po -> protected TP4056 -> power switch -> TPS63802 3.3V
                                                        |
                         ESP32 + BU01 + ST7789 + GY-511 + MAX30102
```

- Share ground across every module.
- Add bulk and local decoupling capacitors.
- Verify TPS63802 output during concurrent UWB and ESP-NOW traffic.
- Keep antenna regions away from metal and the battery.

## Mounting

Use the same GY-511-to-display orientation convention as Node A. If physical assembly differs, select the correct compile-time X/Y swap and sign mapping for Node B.

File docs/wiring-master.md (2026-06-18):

# Master Wiring

The master uses ESP32-WROOM-32 + B&T BU01 DW1000 LDO UWB breakout and battery power.

## Power

```text
602030 Li-Po 3.7V -> TP4056 Type-C with protection -> power switch -> TPS63802 buck-boost -> 3.3V rail -> ESP32 + BU01
```

Add:

- Bulk capacitor near the TPS63802 output and ESP32/UWB power input.
- Local 10uF and 0.1uF decoupling near modules.
- Shared ground between charger output, buck-boost module, ESP32, and BU01.

## UWB Warning

B&T BU01 DW1000 LDO must use 3.3V-compatible signal pins. Confirm the exact power input pin before wiring; the LDO label does not automatically make every pin 5V tolerant.

## Signal Wiring

Confirm whether the B&T BU01 DW1000 LDO breakout is configured for UART or SPI before final wiring. Keep wires short and document actual pins in `docs/pin-map.md`.

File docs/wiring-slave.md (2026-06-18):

# Slave Wiring

Each slave uses ESP32-WROOM-32, B&T BU01 DW1000 LDO UWB breakout, an IPS TFT LCD 240x240 ST7789 display, GY-511/LSM303DLHC motion/compass sensor, MAX30102 BPM sensor, SOS button, and battery power.

## Power

```text
602030 Li-Po 3.7V -> TP4056 Type-C with protection -> power switch -> TPS63802 buck-boost -> 3.3V rail
```

All modules should share common ground. Add power-filter capacitors near the buck-boost output and local decoupling near the ESP32, BU01, display, and sensors.

## ST7789 240x240 Display

Use the display module pins `SCL`, `SDA`, `BLC`, `DC`, and `RES`. On this ST7789 module, `SCL` is SPI `SCK` and `SDA` is SPI `MOSI`; they are not I2C pins. `BLC` should use a PWM-capable GPIO if brightness control is needed. `DC` is the data/command pin and `RES` is the reset pin. The module has no `CS` pin, so firmware uses no-CS ST7789 mode; in Wokwi, the simulated `CS` pin is tied to ground.

## MAX30102

Use I2C wiring. Confirm pullups and module voltage compatibility before long testing.

## GY-511 / LSM303DLHC

Use I2C wiring. It can share the I2C bus with MAX30102 if the breakout addresses and pullups are compatible. It does not share the ST7789 display bus because the display uses SPI.

## SOS Button

Wire as a momentary digital input with a pullup or pulldown resistor. Debounce in firmware and keep it reachable from the enclosure.

## BU01 UWB

Use 3.3V-safe signal levels. Confirm the exact power input pin and UART/SPI mode on the B&T BU01 DW1000 LDO breakout before final wiring. Keep the antenna area clear of metal, battery, and dense wiring when possible.

## Battery Monitor

Use a resistor divider into an ESP32 ADC pin. Do not feed raw Li-Po voltage into an ADC pin.

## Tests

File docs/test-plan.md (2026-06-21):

# Two-Node Radar MVP Test Plan

Current product nodes:

- Node A / DW1000 Anchor: `0C:8A:D3:7C:E5:A4`
- Node B / DW1000 Tag: `1C:75:C4:F4:E9:D4`

The diagnostic firmware may still print `MASTER / ANCHOR` and `SLAVE 1 / TAG`. Those strings map to Node A and Node B; they do not define an application Master/Slave architecture.

## Completed Module Bring-Up

- [x] ESP32 blink upload succeeds.
- [x] STA MAC addresses are recorded for the two current product boards.
- [x] ZJY-IPS130-V2.0 displays colors, text, and map points with manual reset, `SPI_MODE3`, and 8 MHz transactions.
- [x] I2C scanner detects GY-511 addresses `0x19` and `0x1E`.
- [x] I2C scanner detects MAX30102 address `0x57`.
- [x] MAX30102 reads raw IR.
- [x] MAX30102 BPM calculation firmware builds successfully.
- [x] BPM output has been compared with a reference heart-rate measurement.
- [x] LSM303DLHC reads acceleration, compass, and `0-359 deg` heading values.
- [x] Protected TP4056 Type-C module charges the 602030 Li-Po safely.

## Node Hardware Parity

- [ ] Add ST7789, GY-511, and MAX30102 to Node A.
- [ ] Confirm Node A display pins `14/13/25/26/27`.
- [ ] Confirm Node A passes the corrected `st7789_display_test` startup sequence.
- [ ] Confirm Node A GY-511 and MAX30102 share I2C `21/22`.
- [ ] Confirm Node B uses the same current pin contract.
- [ ] Confirm both nodes remain stable with display, sensors, UWB, and ESP-NOW active.
- [ ] Confirm TPS63802 output during ESP32 radio and UWB bursts.
- [ ] Record GY-511 physical X/Y orientation relative to display top on both nodes.

## GY-511 Motion and Heading

- [x] Run `firmware/tests/i2c_scanner_test`.
- [x] Confirm accelerometer address `0x19`.
- [x] Confirm magnetometer address `0x1E`.
- [x] Confirm MAX30102 remains separate at `0x57` on the shared bus.
- [x] Run `firmware/tests/gy511_test`.
- [x] Confirm Serial Monitor prints `GY-511 init OK`.
- [ ] Tilt the module and confirm accelerometer X/Y/Z changes.
- [ ] Rotate the module and confirm magnetometer X/Y/Z changes.
- [x] Confirm heading stays in `0-359 deg`.
- [ ] Validate compile-time X/Y swap and sign mapping for Node A.
- [ ] Validate compile-time X/Y swap and sign mapping for Node B.
- [ ] Confirm weak acceleration does not change the movement bearing.
- [ ] Confirm clear forward/right acceleration produces the expected north-up bearing.

## UWB Pair Diagnostic

References:

- `docs/uwb-pair-ranging-ap-implementation-th.md`
- `docs/arduino-ide-uwb-pair-test.md`
- `docs/arduino-ide-uwb-pair-test-th.md`

- [x] Initialize B&T BU01 DW1000 LDO through default SPI.
- [x] Keep the no-CS ST7789 on a separate `SPIClass` bus.
- [x] Build diagnostic `master` and `tag` environments.
- [x] Confirm `BLINK -> RANGING_INIT -> POLL -> RANGE_REPORT`.
- [x] Add 5-second discovery and 15-second connected recovery.
- [x] Capture 1m raw range at antenna delay `16384` (approximately 2.48m).
- [x] Capture 1m raw range at antenna delay `16640` (approximately 0.26m).
- [x] Select calibrated antenna delay `16555` (approximately 0.94m at the calibration pass).
- [x] Capture unfiltered 2m and 5m results.
- [x] Enable the five-sample application median filter.
- [x] Pass filtered 5m test: 471 samples/60s, 4.999m average, no reconnect/recovery.
- [x] Accept 10m retest with limitation: 138 samples/30s, median 10.17m, one inactive/recovery.
- [x] Record 20m result: median 20.26m, 26 samples/30s, three recoveries.
- [x] Confirm Serial and diagnostic web monitor show live distance, RX power, and quality.
- [ ] Re-run Node A-Node B ranging after both nodes carry the complete Radar hardware load.
- [ ] Confirm production ranging works without AP/webserver code.

## Shared Radar Firmware

- [ ] Create `firmware/radar_node` with `node_a_anchor` and `node_b_tag` environments.
- [ ] Confirm both environments build from the same sources.
- [ ] Confirm Radar state updates every approximately 150 ms without blocking UWB polling.
- [ ] Confirm distance EMA initializes from the first valid range.
- [ ] Confirm cumulative distance change greater than `0.25m` triggers bearing evaluation.
- [ ] Confirm stable distance retains the previous Peer angle.
- [ ] Confirm angle smoothing crosses `0/360 deg` through the shortest path.

## ESP-NOW Peer Data

- [ ] Confirm Node A receives Node B BPM.
- [ ] Confirm Node B receives Node A BPM.
- [ ] Confirm invalid/no-finger BPM displays `PEER BPM:--`.
- [ ] Confirm 3-second ESP-NOW staleness changes only the BPM state.
- [ ] Confirm an accepted local bearing is sent immediately.
- [ ] Confirm the receiving node applies reciprocal `+180 deg` bearing.
- [ ] Confirm one moving node updates both displays.

## Radar Display

- [ ] Draw outer/inner circles, cross lines, north marker, and center dot.
- [ ] Show Node A and Node B labels correctly.
- [ ] Show an active Peer dot while UWB is current.
- [ ] Show `WAITING` and no dot before the first valid range.
- [ ] Keep the last dot as a gray outline after `UWB LOST`.
- [ ] Show active range as `R:5m`, `R:10m`, `R:20m`, or `R:40m`.
- [ ] Expand scale above 90% of the current band.
- [ ] Shrink scale only after 10 seconds below 35%.
- [ ] Freeze scale while UWB is lost.
- [ ] Show Peer BPM and distance at the bottom.
- [ ] Confirm both screens update without unacceptable flicker.

## Power and Field Tests

- [ ] Run each complete node on battery for 30 minutes.
- [ ] Run both nodes together for one hour.
- [ ] Check regulator temperature and ESP32 resets.
- [ ] Test one moving node at a time in open space.
- [ ] Test body obstruction, trees, walking, out-of-range, and recovery.
- [ ] Record simultaneous movement as an MVP limitation rather than an accuracy pass criterion.

Record evidence in:

- `test-logs/uwb-pair-test.md`
- `test-logs/radar-mvp-test.md`
- `test-logs/battery-test.md`
- `test-logs/field-test.md`

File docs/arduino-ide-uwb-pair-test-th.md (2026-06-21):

# คู่มือ Arduino IDE: UWB Pair Test

คู่มือนี้ใช้สำหรับรัน S.T.A.T `uwb_pair_test` ด้วย Arduino IDE แทน PlatformIO

> ขอบเขต diagnostic: เทสต์นี้ยังเก็บ AP monitor และชื่อ role แบบเดิมไว้ แต่ production Radar firmware จะไม่มี AP, webserver หรือ application-level Master/Slave

เทสต์นี้ใช้วัดระยะจริงระหว่าง Node A/Anchor และ Node B/Tag โดย Anchor ฝั่ง diagnostic จะสร้าง Wi-Fi AP ชื่อ `S.T.A.T-UWB` และมีหน้ามอนิเตอร์ที่ `http://192.168.4.1`

## ฮาร์ดแวร์

ใช้ ESP32 2 ตัว และโมดูล B&T BU01 DW1000 LDO 2 ตัว โดยต่อสายเหมือนกันทั้งสอง node

| สัญญาณ BU01 / DW1000 | ขา ESP32 | หมายเหตุ |
|---|---:|---|
| SCK | GPIO18 | SPI clock หลัก |
| MISO | GPIO19 | SPI MISO หลัก |
| MOSI | GPIO23 | SPI MOSI หลัก |
| CS / SS | GPIO5 | chip select ของ DW1000 |
| IRQ | GPIO34 | ขา interrupt แบบ input-only |
| RST | GPIO4 | reset ของ DW1000 |
| VCC | 3.3V หรือ VIN ที่ยืนยันแล้ว | ดู label บน breakout จริงก่อนใช้ VIN |
| GND | GND | ต้องต่อกราวด์ร่วมกัน |

อย่าต่อขาที่ไม่แน่ใจของ BU01 เข้ากับ 5V ขาสัญญาณของ DW1000 ต้องปลอดภัยกับระดับ 3.3V

## ติดตั้ง Arduino IDE และ ESP32

1. ติดตั้ง Arduino IDE 2.x
2. เพิ่ม ESP32 board support ใน Boards Manager
3. เลือกบอร์ด `ESP32 Dev Module` หรือบอร์ด ESP32 ที่ตรงกับของคุณ
4. ตั้ง Serial Monitor เป็น baud rate `115200`

## ติดตั้ง DW1000 Library ที่ patch แล้ว

อย่าติดตั้ง DW1000 library ตัว upstream ที่ยังไม่ patch จาก Library Manager สำหรับเทสต์นี้ เพราะ library เก่ามีปัญหา build กับ ESP32

ให้ใช้ library ที่ patch แล้วใน repo นี้:

```text
C:\Work\Fastwork\BPMWATCH\lib\DW1000
```

copy folder นี้ไปไว้ใน Arduino libraries folder:

```text
C:\Users\<your-user>\Documents\Arduino\libraries\DW1000
```

หลัง copy แล้ว ให้ตรวจว่ามีไฟล์เหล่านี้:

```text
Documents\Arduino\libraries\DW1000\src\DW1000.cpp
Documents\Arduino\libraries\DW1000\src\DW1000Ranging.cpp
```

ไฟล์ `DW1000.cpp` ที่ patch แล้วต้อง guard `SPI.usingInterrupt(...)` แบบนี้:

```cpp
#if !defined(ESP8266) && !defined(ARDUINO_ARCH_ESP32)
  SPI.usingInterrupt(digitalPinToInterrupt(irq));
#endif
```

ไฟล์ `DW1000Ranging.cpp` ที่ patch แล้วต้องมี fallback return ท้าย `detectMessageType(...)`:

```cpp
return -1;
```

หลัง copy library แล้ว ให้ restart Arduino IDE

## สร้าง Arduino Sketch

Arduino IDE ต้องการไฟล์ `.ino` อยู่ใน folder ที่มีชื่อเดียวกัน

ไฟล์ sketch พร้อมใช้งานอยู่ที่:

```text
C:\Work\Fastwork\BPMWATCH\arduino\uwb_pair_test_arduino
```

เปิดไฟล์ `uwb_pair_test_arduino.ino` ด้วย Arduino IDE แล้วเลือก role ที่บรรทัดบนสุด:

```cpp
#define UWB_IS_MASTER 1
```

ใช้ค่า `1` สำหรับ Node A/Anchor และใช้ค่า `0` สำหรับ Node B/Tag ชื่อ macro เดิมยังคงอยู่เพื่อให้ตรงกับ sketch ที่ผ่านการทดสอบแล้ว

## Upload และตรวจ output

1. ตั้ง `UWB_IS_MASTER` เป็น `1` เลือก COM port ของ Node A แล้วกด Upload
2. ตั้ง `UWB_IS_MASTER` เป็น `0` เลือก COM port ของ Node B แล้วกด Upload
3. เปิด Serial Monitor ที่ `115200` เพื่อดูสถานะการเชื่อมต่อและค่าระยะ
4. เชื่อมต่อโทรศัพท์หรือคอมพิวเตอร์กับ Wi-Fi `S.T.A.T-UWB` รหัสผ่าน `statuwb123`
5. เปิด `http://192.168.4.1` เพื่อดู distance, RX power, quality และจำนวนครั้งที่อัปเดต

output ที่ควรเห็น:

ข้อความ `MASTER / ANCHOR` ด้านล่างเป็น string เดิมของ diagnostic firmware และหมายถึง Node A/Anchor ในสถาปัตยกรรมปัจจุบัน

```text
S.T.A.T real UWB pair ranging test
Role: MASTER / ANCHOR
Wi-Fi AP: S.T.A.T-UWB
Password: statuwb123
Monitor: http://192.168.4.1
UWB peer connected: short address 0x...
Range #1: 1.02 m, RX -76.4 dBm, quality 8.0
```

## Troubleshooting

ถ้าเจอ error นี้:

```text
'class SPIClass' has no member named 'usingInterrupt'
```

แปลว่า Arduino IDE กำลังใช้ DW1000 library ที่ยังไม่ patch ให้ลบ DW1000 library ตัวอื่นออกจาก `Documents\Arduino\libraries` แล้ว copy `lib\DW1000` จาก repo นี้เข้าไปใหม่

ถ้า upload ไม่ผ่าน ให้กดปุ่ม `BOOT` บน ESP32 ค้างไว้ตอนเริ่ม upload แล้วปล่อยหลัง Arduino IDE แสดง `Connecting...`

ถ้า Serial Monitor ไม่มีข้อความ ให้ตรวจ:

- baud rate เป็น `115200`
- เลือก COM port ถูกต้อง
- ลองกด reset บน ESP32 หลังเปิด Serial Monitor

ถ้า DW1000 init ได้ แต่ real ranging ไม่ผ่าน ให้ตรวจ:

- BU01 มีไฟเลี้ยงนิ่งพอ
- สาย SPI สั้นและต่อถูกต้อง
- CS ต่อ GPIO5
- IRQ ต่อ GPIO34
- ทั้งสอง node ใช้ firmware และ timing schedule แบบเดียวกัน

## กฎสำคัญเรื่อง SPI

สำหรับ BPMWATCH ให้ DW1000 ใช้ global `SPI` bus หลัก เพราะ library นี้เรียกใช้ `SPI` โดยตรง

จอ ST7789 แบบไม่มี CS ต้องอยู่บน `SPIClass` อีก bus หนึ่ง อย่าเอา ST7789 no-CS ไปอยู่ SPI bus เดียวกับ DW1000

เอกสาร production ปัจจุบันอยู่ที่ `docs/architecture.md`, `docs/pin-map.md`, `docs/wiring-node-a.md` และ `docs/wiring-node-b.md`

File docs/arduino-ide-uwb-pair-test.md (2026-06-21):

# Arduino IDE Guide: UWB Pair Test

Thai version: `docs/arduino-ide-uwb-pair-test-th.md`

This guide is for running the S.T.A.T `uwb_pair_test` with Arduino IDE instead of PlatformIO.

> Diagnostic scope: this test keeps its historical AP monitor and legacy role labels. Production Radar firmware has no AP, webserver, or application-level Master/Slave.

This test performs real two-node ranging between Node A/Anchor and Node B/Tag. The diagnostic Anchor creates the `S.T.A.T-UWB` Wi-Fi access point and serves a live monitor at `http://192.168.4.1`.

## Hardware

Use two ESP32 boards and two B&T BU01 DW1000 LDO modules with the same wiring on both nodes.

| BU01 / DW1000 Signal | ESP32 Pin | Notes |
|---|---:|---|
| SCK | GPIO18 | Default SPI clock |
| MISO | GPIO19 | Default SPI MISO |
| MOSI | GPIO23 | Default SPI MOSI |
| CS / SS | GPIO5 | DW1000 chip select |
| IRQ | GPIO34 | Input-only interrupt pin |
| RST | GPIO4 | DW1000 reset |
| VCC | 3.3V or confirmed module VIN | Check your exact breakout label before using VIN |
| GND | GND | Common ground required |

Do not connect unknown BU01 pins to 5V. The DW1000 signal pins must be 3.3V-safe.

## Install Arduino IDE Support

1. Install Arduino IDE 2.x.
2. Add ESP32 board support in Boards Manager.
3. Select `ESP32 Dev Module` or the matching ESP32 board.
4. Set Serial Monitor baud rate to `115200`.

## Install The Patched DW1000 Library

Do not install the unpatched upstream DW1000 library from Library Manager for this test. The old library has ESP32 build issues.

Use the patched copy already stored in this repo:

```text
C:\Work\Fastwork\BPMWATCH\lib\DW1000
```

Copy that folder into your Arduino libraries folder:

```text
C:\Users\<your-user>\Documents\Arduino\libraries\DW1000
```

After copying, confirm these patched files exist:

```text
Documents\Arduino\libraries\DW1000\src\DW1000.cpp
Documents\Arduino\libraries\DW1000\src\DW1000Ranging.cpp
```

The patched `DW1000.cpp` must guard `SPI.usingInterrupt(...)` like this:

```cpp
#if !defined(ESP8266) && !defined(ARDUINO_ARCH_ESP32)
  SPI.usingInterrupt(digitalPinToInterrupt(irq));
#endif
```

The patched `DW1000Ranging.cpp` must return a fallback value at the end of `detectMessageType(...)`:

```cpp
return -1;
```

Restart Arduino IDE after copying the library.

## Create The Arduino Sketch

Arduino IDE expects an `.ino` file inside a folder with the same name.

The sketch is already available here:

```text
C:\Work\Fastwork\BPMWATCH\arduino\uwb_pair_test_arduino
```

Open `uwb_pair_test_arduino.ino` in Arduino IDE. The role switch is at the top:

```cpp
#define UWB_IS_MASTER 1
```

Use `1` for Node A/Anchor. Use `0` for Node B/Tag. The macro name is retained for compatibility with the tested sketch.

## Upload And Check Output

1. Set `UWB_IS_MASTER` to `1`, select Node A's COM port, and upload.
2. Set `UWB_IS_MASTER` to `0`, select Node B's COM port, and upload.
3. Open Serial Monitor at `115200` to see connection and range messages.
4. Connect a phone or computer to Wi-Fi `S.T.A.T-UWB` using password `statuwb123`.
5. Open `http://192.168.4.1` to monitor distance, RX power, quality, and update count.

Expected output:

The literal `MASTER / ANCHOR` text below is a legacy diagnostic string. It means Node A/Anchor in the current architecture.

```text
S.T.A.T real UWB pair ranging test
Role: MASTER / ANCHOR
Wi-Fi AP: S.T.A.T-UWB
Password: statuwb123
Monitor: http://192.168.4.1
UWB peer connected: short address 0x...
Range #1: 1.02 m, RX -76.4 dBm, quality 8.0
```

## Troubleshooting

If you see this error:

```text
'class SPIClass' has no member named 'usingInterrupt'
```

Arduino IDE is using an unpatched DW1000 library. Remove other `DW1000` libraries from `Documents\Arduino\libraries`, then copy this repo's `lib\DW1000` folder again.

If upload fails, hold `BOOT` on the ESP32 while upload starts, then release it after Arduino IDE shows `Connecting...`.

If Serial Monitor prints nothing, check:

- Baud rate is `115200`.
- The selected COM port is correct.
- ESP32 reset button was pressed after opening Serial Monitor.

If DW1000 initializes but real ranging fails, check:

- BU01 has stable power.
- All SPI wires are short and correct.
- CS is connected to GPIO5.
- IRQ is connected to GPIO34.
- Both nodes use the same tested ranging mode, antenna delay, and vendored library.

## Important SPI Rule

For BPMWATCH, DW1000 uses the default global `SPI` bus because the library directly owns `SPI`.

The no-CS ST7789 display must stay on a separate `SPIClass` bus. Do not place a no-CS ST7789 display on the same SPI bus as DW1000.

For current production architecture and wiring, see `docs/architecture.md`, `docs/pin-map.md`, `docs/wiring-node-a.md`, and `docs/wiring-node-b.md`.

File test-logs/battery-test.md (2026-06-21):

# Two-Node Radar Battery Test Log

Record tests only after the node carries ESP32, BU01, ST7789, GY-511, MAX30102, charger, regulator, and battery.

| Date | Node | Runtime | Start voltage | End voltage | UWB/ESP-NOW state | Resets | Regulator temperature/notes |
|---|---|---:|---:|---:|---|---:|---|
| Not tested | Node A | - | - | - | - | - | Complete hardware pending |
| Not tested | Node B | - | - | - | - | - | Complete hardware pending |

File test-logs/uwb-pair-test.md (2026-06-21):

# UWB Pair Test Log

Current product pair: Node A/Anchor (`0C:8A:D3:7C:E5:A4`) and Node B/Tag (`1C:75:C4:F4:E9:D4`). Rows originally recorded as `M-S1` are renamed only for current terminology; numeric evidence is unchanged.

|Date|Pair|Expected Distance|Measured Distance|Quality|Notes|
|-|-|-:|-:|-:|-|
|2026-06-21|Node A-Node B|1.00 m|\~2.48 m raw|\~25-32|Antenna delay 16384, filter off|
|2026-06-21|Node A-Node B|1.00 m|\~0.26 m raw|\~50-70|Antenna delay 16640, filter off|
|2026-06-21|Node A-Node B|1.00 m|\~0.94 m raw|\~50-60|Antenna delay 16555, filter off|
|2026-06-21|Node A-Node B|2.00 m|\~2.32 m raw|\~40-60|Antenna delay 16555, filter off|
|2026-06-21|Node A-Node B|5.00 m|\~4.70 m raw|\~14-51|Antenna delay 16555, filter off; RX -95 to -98 dBm; one reconnect|
|2026-06-21|Node A-Node B|2.00 m|2.03-2.08 m|\~54-79|Antenna delay 16555, filter 5; 170 samples without reconnect|
|2026-06-21|Node A-Node B|5.00 m|4.40-5.55 m; avg 4.999 m|avg 71.6|Antenna delay 16555, filter 5; 471 samples/60s; RX avg -93.44 dBm; no reconnect/recovery|
|2026-06-21|Node A-Node B|10.00 m|9.924 m avg first window; 11.24 m median second window|avg 81.3 first window|Failed stability: one 104.25m outlier, 6 recoveries across 90s; RX avg -95 to -96 dBm|
|2026-06-21|Node A-Node B|10.00 m|9.99-10.24 m; median 10.17 m|avg 79.8|Accepted 30s retest: 138 samples, no outliers, RX avg -96.42 dBm; one peer inactive/recovery|
|2026-06-21|Node A-Node B|20.00 m|20.23-20.29 m; median 20.26 m|avg 78.6|Accuracy passed, continuity limited: 26 samples/30s, RX avg -97.69 dBm, one peer inactive and three recoveries|

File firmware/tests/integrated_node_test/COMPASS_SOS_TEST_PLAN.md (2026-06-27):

# Compass, Heading UI, and SOS Test Plan

This phase keeps UWB as distance-only. Compass heading is the local wearer/device heading, not a measured bearing to the peer. The radar dot remains a movement/demo angle and is transformed into a north-oriented UI angle with local heading.

## Pin Assumptions

| Function | ESP32 pin | Notes |
| --- | --- | --- |
| GY-511 / LSM303DLHC SDA | GPIO21 | Shared I2C with MAX30102 |
| GY-511 / LSM303DLHC SCL | GPIO22 | Shared I2C with MAX30102 |
| GY-511 accel I2C | 0x19 or 0x18 | SA0 variant fallback |
| GY-511 magnetometer I2C | 0x1E | Required for heading |
| SOS button | GPIO32 | `INPUT_PULLUP`, active LOW |

## Build Tests

- Native policy tests: `C:\Users\pipat\.platformio\penv\Scripts\platformio.exe test -e native`
- Compass enabled: `C:\Users\pipat\.platformio\penv\Scripts\platformio.exe run -e node_a_anchor_espnow_range`
- Compass disabled: `C:\Users\pipat\.platformio\penv\Scripts\platformio.exe run -e node_a_anchor_espnow_range_no_compass`
- SOS enabled: `C:\Users\pipat\.platformio\penv\Scripts\platformio.exe run -e node_b_tag_espnow_display`
- SOS disabled: `C:\Users\pipat\.platformio\penv\Scripts\platformio.exe run -e node_b_tag_espnow_display_no_sos`

## Compass Test

- Start each node and confirm `COMPASS=OK`.
- Confirm the I2C scan includes `1E` and either `19` or `18`.
- Rotate the device and confirm `HDG` changes through `0..359`.
- Confirm `MAG_RAW=x,y,z`, `CS#`, and `CAGE` update while UWB ranging remains active.
- Optional calibration capture: build with `-D BPMWATCH_COMPASS_CAL_LOG=true`, rotate the node slowly, and record `COMPASS_CAL MAG_MIN=... MAG_MAX=...`.
- Confirm `LR_OK=1`, `LR_FAIL=0`, and `IRQMODE=IRQ` are still present in normal logs.

## ESP-NOW Heading Test

- Start both nodes with ESP-NOW enabled.
- Confirm each node logs `ESPNOW=OK`.
- Rotate Node A and confirm Node B logs/displays `REMOTE_HDG`.
- Rotate Node B and confirm Node A logs `REMOTE_HDG`.

## SOS Test

- Hold the SOS button on Node A for about 1 second.
- Confirm Node A logs `SOS=1`, `SOS_SEQ` increments, and `BTN_EVENT=LONG`.
- Confirm Node B shows the red peer SOS banner and logs `REMOTE_SOS=1`.
- Hold the SOS button again for about 1 second.
- Confirm Node A logs `SOS=0` with a new sequence and Node B clears remote SOS after receiving the cancel packet.
- Power off Node A while SOS is active and confirm Node B clears remote SOS after the 10 second timeout.

## Integrated Test

- Confirm UWB distance still updates at the expected range.
- Confirm ESPNOW counters increment without high `TX_FAIL`.
- Confirm MAX30102 still reports BPM when a finger is present.
- Confirm compass/SOS logs do not spam faster than the normal diagnostics interval.
- Confirm no UI text claims true bearing or peer direction from compass alone.

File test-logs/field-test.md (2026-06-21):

# Two-Node Radar Field Test Log

| Date | Location | Moving node | Scenario | UWB result | Bearing/display result | ESP-NOW/BPM result | Notes |
|---|---|---|---|---|---|---|---|
| Not tested | - | - | Open space | - | - | - | Production Radar firmware pending |
| Not tested | - | - | Body obstruction | - | - | - | Production Radar firmware pending |
| Not tested | - | - | Trees | - | - | - | Production Radar firmware pending |
| Not tested | - | - | Out of range and return | - | - | - | Production Radar firmware pending |

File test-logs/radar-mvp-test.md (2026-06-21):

# Radar MVP Test Log

Use one row per controlled movement or failure-state test. For primary MVP tests, move only one node at a time.

| Date | Moving node | Start/end distance | Distance trend | Expected Peer bearing | Node A display | Node B display | UWB state | Peer BPM state | Range band | Notes |
|---|---|---|---|---:|---|---|---|---|---:|---|
| Not tested | Node A | - | decreasing | - | - | - | - | - | - | Production firmware pending |
| Not tested | Node A | - | increasing | - | - | - | - | - | - | Production firmware pending |
| Not tested | Node B | - | decreasing | - | - | - | - | - | - | Production firmware pending |
| Not tested | Node B | - | increasing | - | - | - | - | - | - | Production firmware pending |

## Failure-State Evidence

| Date | Test | Expected | Observed | Pass | Notes |
|---|---|---|---|---|---|
| Not tested | UWB disconnected after valid range | Last dot remains as gray outline with `UWB LOST` | - | - | - |
| Not tested | ESP-NOW stale for 3 seconds | Radar continues; `PEER BPM:--` | - | - | - |
| Not tested | No valid UWB since boot | `WAITING` with no Peer dot | - | - | - |
| Not tested | Distance stable | Previous Peer angle remains | - | - | - |
| Not tested | Auto-range expansion | Band expands above 90% | - | - | - |
| Not tested | Auto-range shrink | Band shrinks after 10 seconds below 35% | - | - | - |

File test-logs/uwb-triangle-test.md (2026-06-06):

# UWB Triangle Test Log

| Date | dM1 | dM2 | d12 | Map Valid | Notes |
|---|---:|---:|---:|---:|---|
| TODO | TODO | TODO | TODO | TODO | TODO |

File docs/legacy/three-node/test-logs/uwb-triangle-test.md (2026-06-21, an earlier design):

# Legacy UWB Triangle Test Log

> Superseded on 2026-06-21 when BPMWATCH changed to the two-node Radar MVP.

| Date | dM1 | dM2 | d12 | Map Valid | Notes |
|---|---:|---:|---:|---:|---|
| TODO | TODO | TODO | TODO | TODO | TODO |

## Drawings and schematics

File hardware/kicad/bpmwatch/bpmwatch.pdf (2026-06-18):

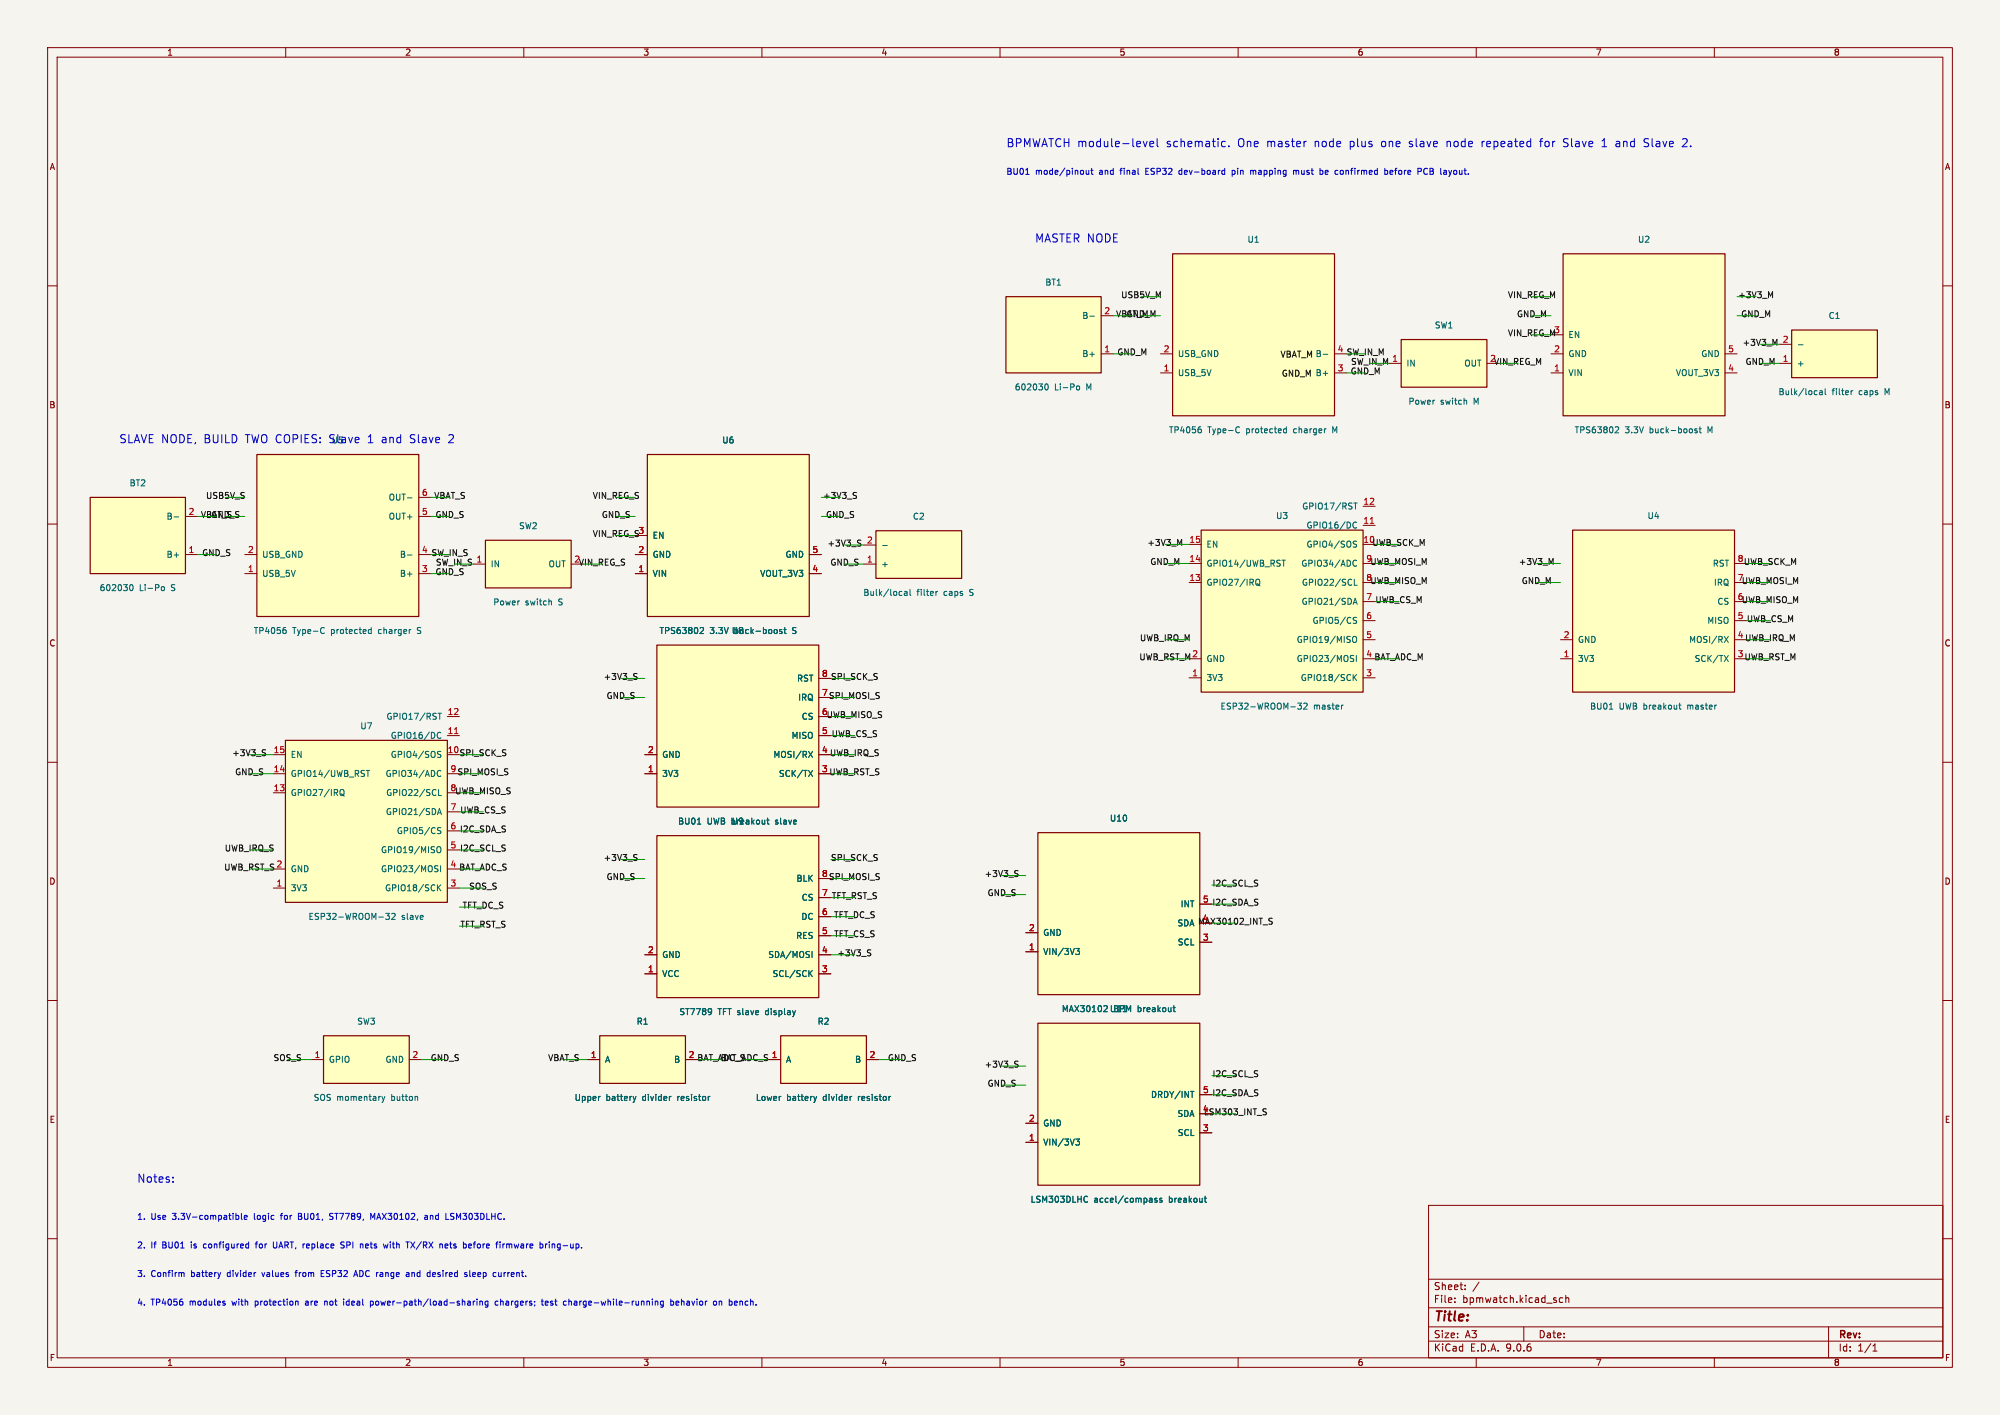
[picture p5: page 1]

SLAVE NODE, BUILD TWO COPIES: Slave 1 and Slave 2

2 R1 Upper battery divider resistor A

Lower battery divider resistor A

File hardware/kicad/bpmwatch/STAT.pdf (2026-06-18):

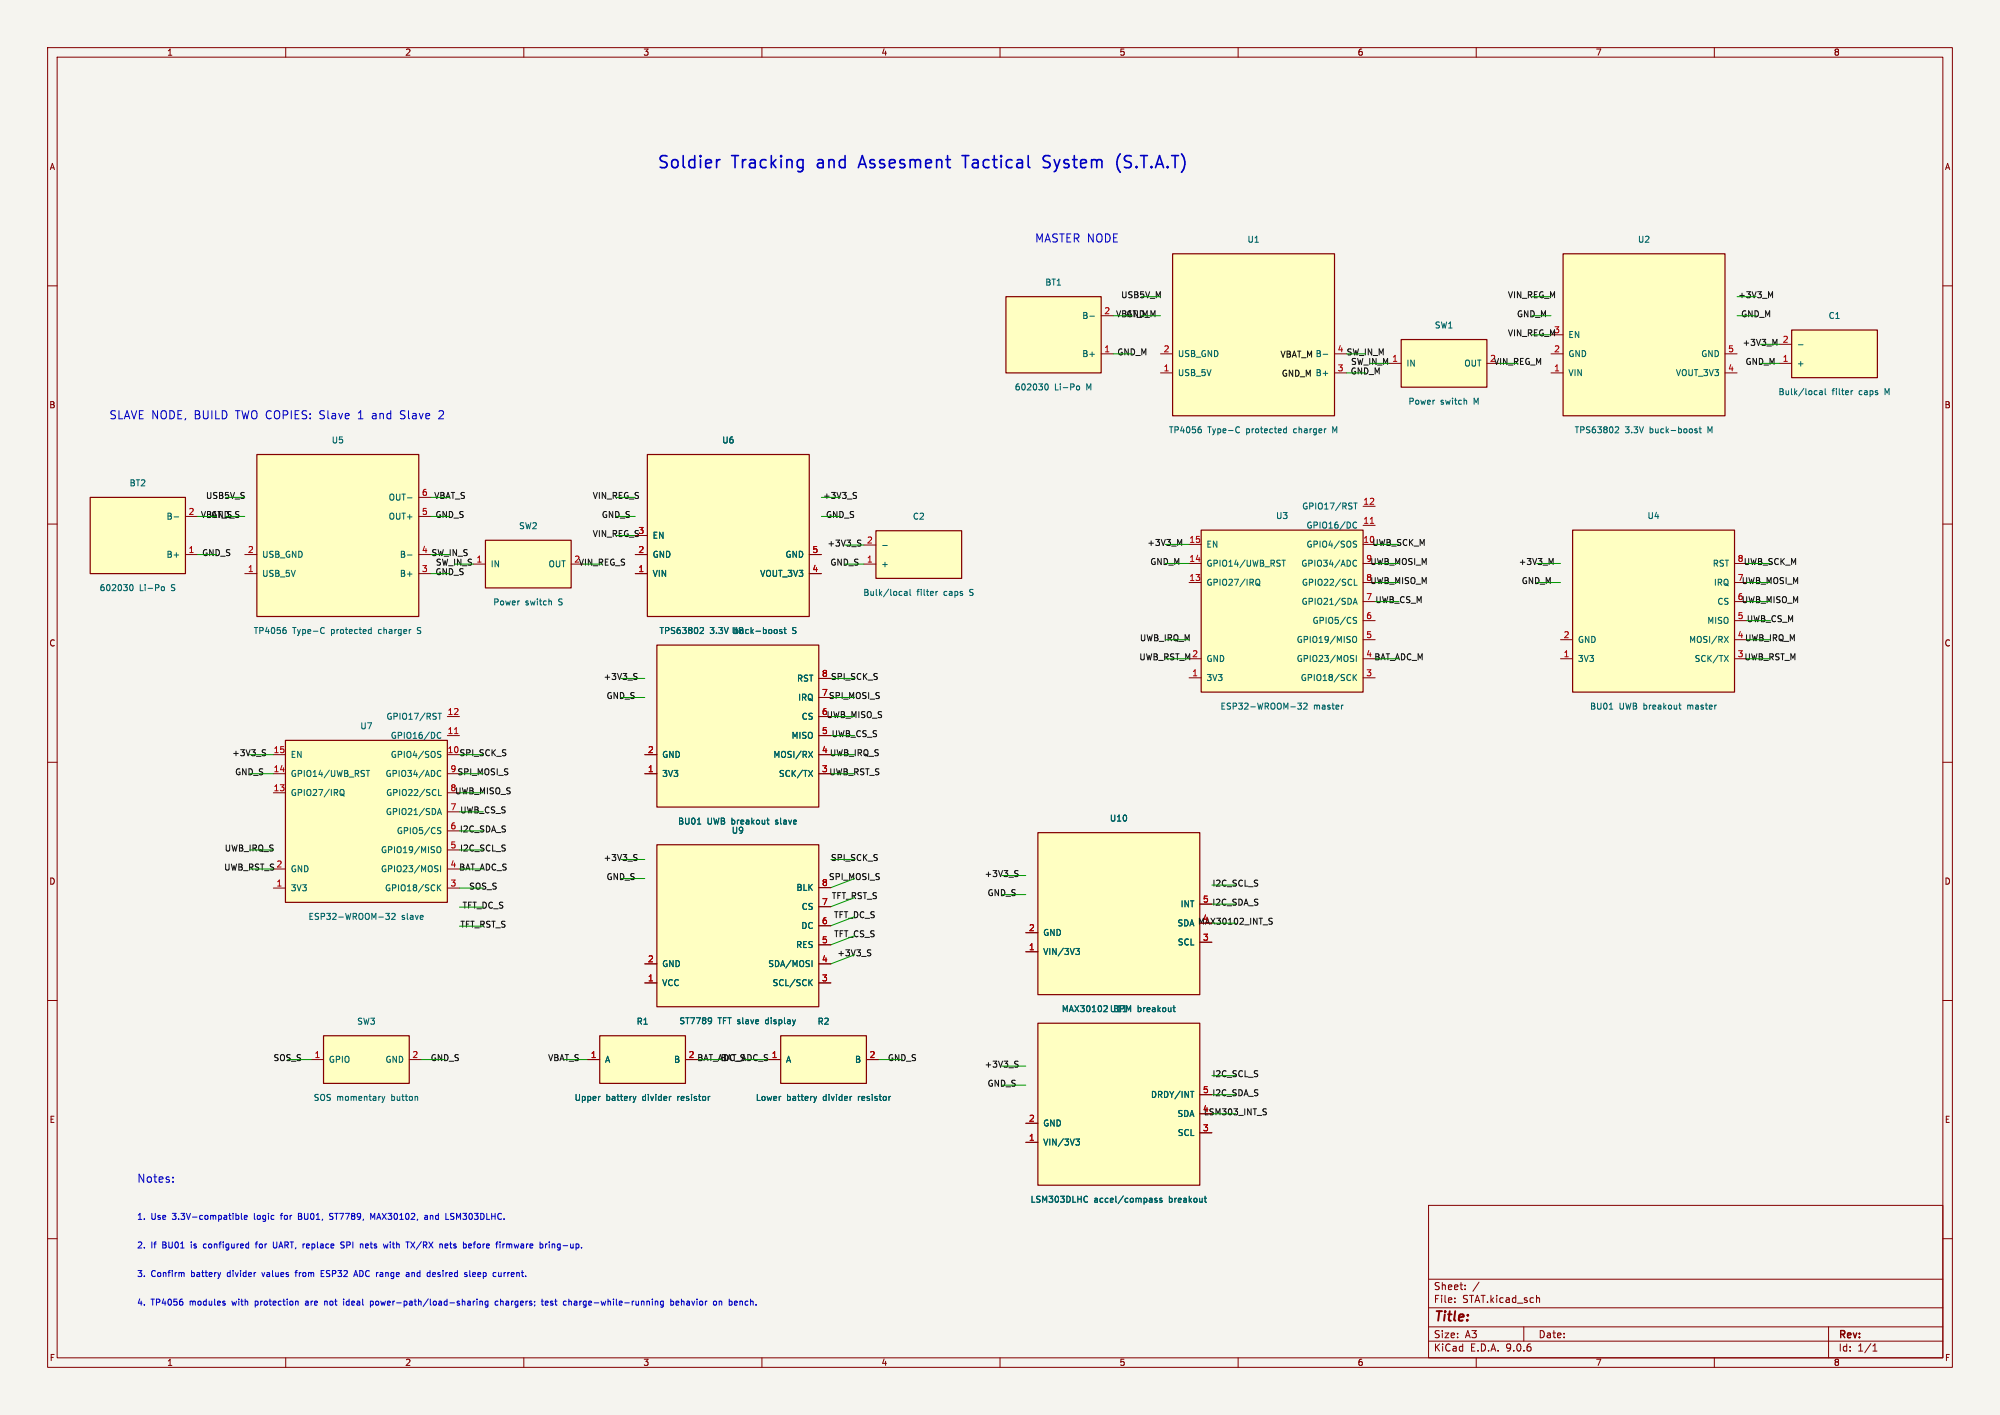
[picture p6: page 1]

Soldier Tracking and Assesment Tactical System (S.T.A.T)

SLAVE NODE, BUILD TWO COPIES: Slave 1 and Slave 2

Lower battery divider resistor A

Lower battery divider resistor

Id: 1/1 Title: File: STAT.kicad_sch Sheet: /

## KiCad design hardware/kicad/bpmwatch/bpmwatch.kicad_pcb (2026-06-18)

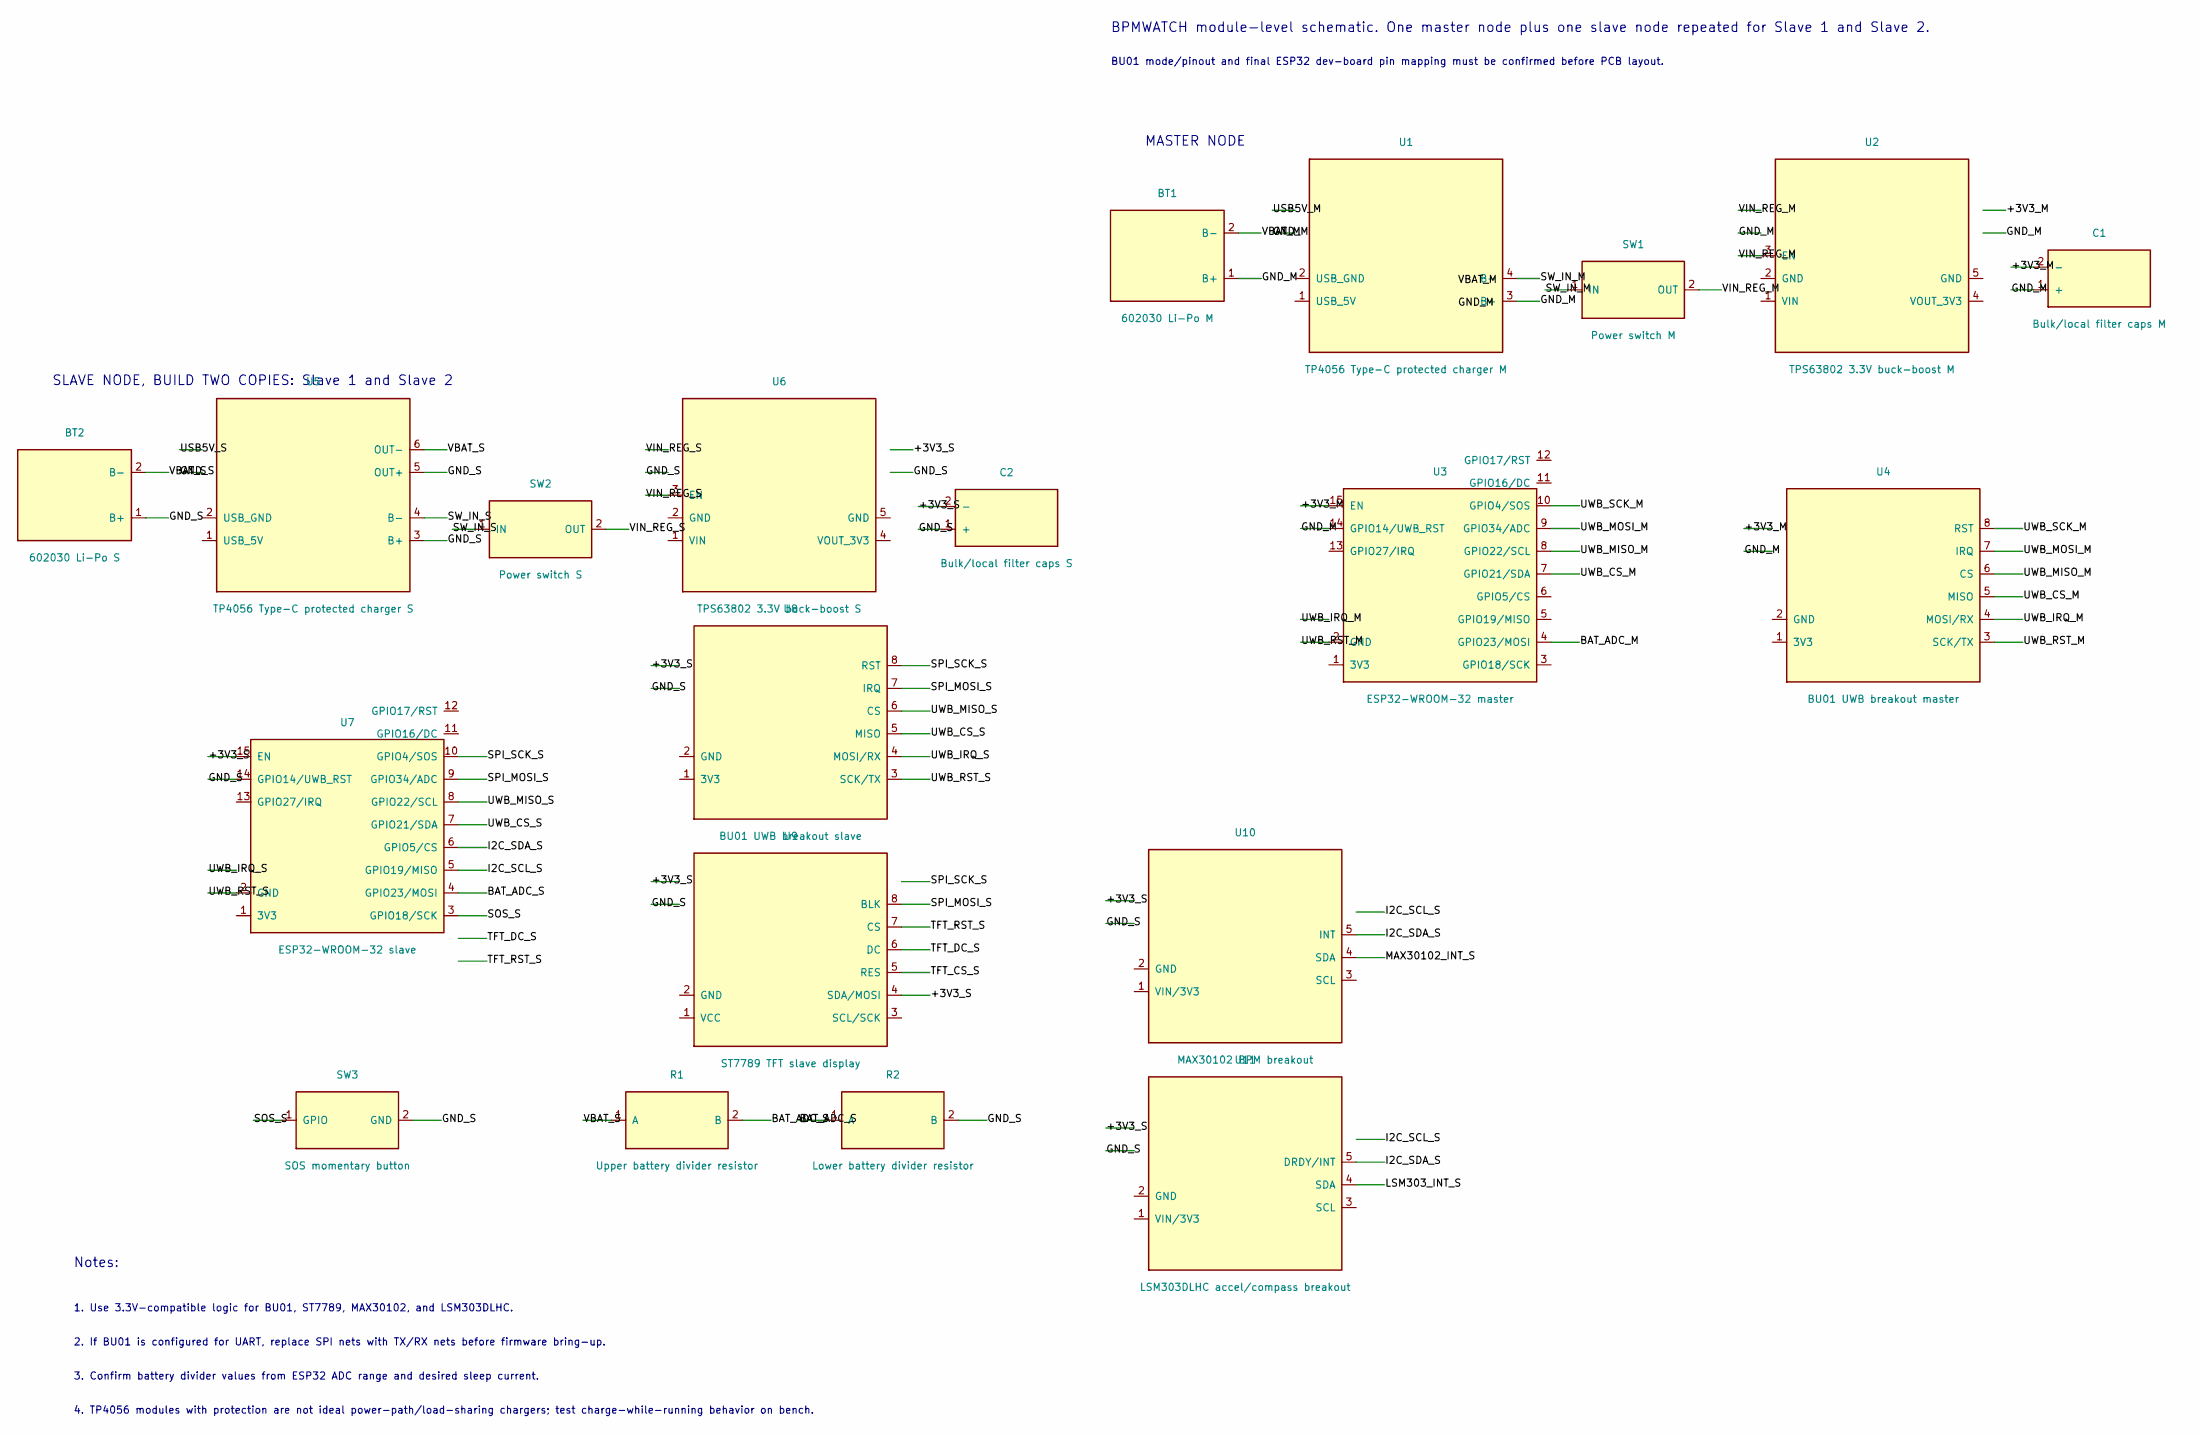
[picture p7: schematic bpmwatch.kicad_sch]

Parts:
BT1: 602030 Li-Po M; JST_PH_S2B-PH-K_1x02_P2.00mm_Horizontal
BT2: 602030 Li-Po S; JST_PH_S2B-PH-K_1x02_P2.00mm_Horizontal
C1: Bulk/local filter caps M; C_0805_2012Metric
C2: Bulk/local filter caps S; C_0805_2012Metric
R1: Upper battery divider resistor; R_0805_2012Metric
R2: Lower battery divider resistor; R_0805_2012Metric
SW1: Power switch M; SW_Slide_SPDT_Straight_CK_OS102011MS2Q
SW2: Power switch S; SW_Slide_SPDT_Straight_CK_OS102011MS2Q
SW3: SOS momentary button; SW_PUSH_6mm_H4.3mm
U1: TP4056 Type-C protected charger M; PinHeader_1x06_P2.54mm_Vertical
U2: TPS63802 3.3V buck-boost M; PinHeader_1x05_P2.54mm_Vertical
U3: ESP32-WROOM-32 master; ESP32-WROOM-32
U4: BU01 UWB breakout master; PinHeader_1x08_P2.54mm_Vertical
U5: TP4056 Type-C protected charger S; PinHeader_1x06_P2.54mm_Vertical
U6: TPS63802 3.3V buck-boost S; PinHeader_1x05_P2.54mm_Vertical
U7: ESP32-WROOM-32 slave; ESP32-WROOM-32
U8: BU01 UWB breakout slave; PinHeader_1x08_P2.54mm_Vertical
U9: ST7789 TFT slave display; PinHeader_1x08_P2.54mm_Vertical
U10: MAX30102 BPM breakout; PinHeader_1x05_P2.54mm_Vertical
U11: LSM303DLHC accel/compass breakout; PinHeader_1x05_P2.54mm_Vertical

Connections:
+3V3_M: C1.2 (-), U3.15 (EN)
+3V3_S: C2.2 (-), U7.15 (EN), U9.4 (SDA/MOSI)
BAT_ADC_M: U3.4 (GPIO23/MOSI)
BAT_ADC_S: R1.2 (B), R2.1 (A), U7.4 (GPIO23/MOSI)
GND_M: BT1.1 (B+), C1.1 (+), U1.3 (B+), U3.14 (GPIO14/UWB_RST)
GND_S: BT2.1 (B+), C2.1 (+), R2.2 (B), SW3.2 (GND), U5.3 (B+), U5.5 (OUT+), U7.14 (GPIO14/UWB_RST)
I2C_SCL_S: U7.5 (GPIO19/MISO)
I2C_SDA_S: U7.6 (GPIO5/CS), U10.5 (INT), U11.5 (DRDY/INT)
LSM303_INT_S: U11.4 (SDA)
MAX30102_INT_S: U10.4 (SDA)
SOS_S: SW3.1 (GPIO), U7.3 (GPIO18/SCK)
SPI_MOSI_S: U7.9 (GPIO34/ADC), U8.7 (IRQ), U9.8 (BLK)
SPI_SCK_S: U7.10 (GPIO4/SOS), U8.8 (RST)
SW_IN_M: SW1.1 (IN), U1.4 (B-)
SW_IN_S: SW2.1 (IN), U5.4 (B-)
TFT_CS_S: U9.5 (RES)
TFT_DC_S: U9.6 (DC)
TFT_RST_S: U9.7 (CS)
UWB_CS_M: U3.7 (GPIO21/SDA), U4.5 (MISO)
UWB_CS_S: U7.7 (GPIO21/SDA), U8.5 (MISO)
UWB_IRQ_M: U4.4 (MOSI/RX)
UWB_IRQ_S: U8.4 (MOSI/RX)
UWB_MISO_M: U3.8 (GPIO22/SCL), U4.6 (CS)
UWB_MISO_S: U7.8 (GPIO22/SCL), U8.6 (CS)
UWB_MOSI_M: U3.9 (GPIO34/ADC), U4.7 (IRQ)
UWB_RST_M: U3.2 (GND), U4.3 (SCK/TX)
UWB_RST_S: U7.2 (GND), U8.3 (SCK/TX)
UWB_SCK_M: U3.10 (GPIO4/SOS), U4.8 (RST)
VBAT_M: BT1.2 (B-)
VBAT_S: BT2.2 (B-), R1.1 (A), U5.6 (OUT-)
VIN_REG_M: SW1.2 (OUT), U2.3 (EN)
VIN_REG_S: SW2.2 (OUT), U6.3 (EN)

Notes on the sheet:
MASTER NODE
BPMWATCH module-level schematic. One master node plus one slave node repeated for Slave 1 and Slave 2.
1. Use 3.3V-compatible logic for BU01, ST7789, MAX30102, and LSM303DLHC.
BU01 mode/pinout and final ESP32 dev-board pin mapping must be confirmed before PCB layout.
Notes:
SLAVE NODE, BUILD TWO COPIES: Slave 1 and Slave 2
2. If BU01 is configured for UART, replace SPI nets with TX/RX nets before firmware bring-up.
4. TP4056 modules with protection are not ideal power-path/load-sharing chargers; test charge-while-running behavior on bench.
3. Confirm battery divider values from ESP32 ADC range and desired sleep current.

Board: 2 copper layers, 20 parts (0 on the bottom side), 22 nets, no tracks yet.

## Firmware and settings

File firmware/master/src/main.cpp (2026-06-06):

#include <Arduino.h>

#include "Packets.h"
#include "RelativeMapSolver.h"
#include "TeamBroadcaster.h"
#include "UwbRanging.h"

namespace {
RelativeMapSolver mapSolver;
TeamBroadcaster broadcaster;
UwbRanging ranging;

SlaveStatusPacket slave1{NODE_SLAVE_1, 82, 95, 1};
SlaveStatusPacket slave2{NODE_SLAVE_2, 91, 92, 1};

uint32_t lastUpdateMs = 0;

int readMasterBatteryPercent() {
  // TODO: Read calibrated battery ADC.
  return 100;
}
}

void setup() {
  Serial.begin(115200);
  delay(500);
  Serial.println("BPMWATCH master starting");

  ranging.begin();
  broadcaster.begin();
}

void loop() {
  if (millis() - lastUpdateMs < 500) {
    return;
  }
  lastUpdateMs = millis();

  const DistancePacket dM1 = ranging.readPair(NODE_MASTER, NODE_SLAVE_1);
  const DistancePacket dM2 = ranging.readPair(NODE_MASTER, NODE_SLAVE_2);
  const DistancePacket d12 = ranging.readPair(NODE_SLAVE_1, NODE_SLAVE_2);

  const TeamMapPacket map = mapSolver.solve(dM1.distanceMeters, dM2.distanceMeters,
                                            d12.distanceMeters, slave1, slave2,
                                            readMasterBatteryPercent());
  broadcaster.broadcast(map);
}

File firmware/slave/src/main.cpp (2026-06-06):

#include <Arduino.h>

#include "BatteryMonitor.h"
#include "DisplayUI.h"
#include "HeartRateSensor.h"
#include "Packets.h"
#include "UwbRanging.h"

#ifndef BPMWATCH_NODE_ID
#define BPMWATCH_NODE_ID 1
#endif

namespace {
BatteryMonitor battery;
DisplayUI display;
HeartRateSensor heartRate;
UwbRanging ranging;

TeamMapPacket latestMap{};
uint32_t lastStatusMs = 0;
uint32_t lastDrawMs = 0;

void sendStatusPacket() {
  SlaveStatusPacket status{};
  status.id = BPMWATCH_NODE_ID;
  status.bpm = heartRate.readBpm();
  status.battery = battery.readPercent();
  status.signal = 1;

  Serial.print("Send status node ");
  Serial.print(status.id);
  Serial.print(" BPM ");
  Serial.print(status.bpm);
  Serial.print(" battery ");
  Serial.println(status.battery);

  // TODO: Send SlaveStatusPacket to master.
}

void receiveMockMap() {
  // TODO: Replace with real TeamMapPacket receive callback.
  latestMap.masterX = 0.0f;
  latestMap.masterY = 0.0f;
  latestMap.slave1X = 3.0f;
  latestMap.slave1Y = 0.0f;
  latestMap.slave2X = 3.0f;
  latestMap.slave2Y = 4.0f;
  latestMap.masterBattery = 100;
  latestMap.slave1Bpm = 82;
  latestMap.slave1Battery = 95;
  latestMap.slave2Bpm = 91;
  latestMap.slave2Battery = 92;
  latestMap.mapValid = 1;
}
}

void setup() {
  Serial.begin(115200);
  delay(500);
  Serial.println("BPMWATCH slave starting");

  battery.begin();
  heartRate.begin();
  display.begin();
  ranging.begin();
}

void loop() {
  ranging.poll();
  receiveMockMap();

  if (millis() - lastStatusMs >= 300) {
    lastStatusMs = millis();
    sendStatusPacket();
  }

  if (millis() - lastDrawMs >= 500) {
    lastDrawMs = millis();
    display.draw(latestMap);
  }
}

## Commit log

2026-06-18 Update BPMWATCH hardware bring-up
    [STAT.kicad_sch, bpmwatch-master.kicad_pcb, bpmwatch-slave.kicad_pcb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]
2026-06-18 Add Arduino IDE UWB pair test guides
2026-06-21 Improve UWB ranging recovery and filtering
2026-06-24 Fix RF_TXCTRL verification and MAX diagnostics
    [DiagnosticsState.h, main.cpp]
2026-06-27 Fix MAX30102 wrist BPM validation
    [DiagnosticsDisplay.cpp, DiagnosticsState.h, FeatureFlags.h]
